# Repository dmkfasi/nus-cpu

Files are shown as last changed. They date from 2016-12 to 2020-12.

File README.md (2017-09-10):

# nus-cpu

This is my own yet another attempt to re-create Nintendo 64 motherboard for a portable, tablet or bartop mod.

I am going after for as much as possible: modular design, reuse of original components, cheapest production costs and the best visual display picture.

There are many bright minds out there whose ideas I try to adopt and develop further. But since I lack of expertise on several electronics topics, this whole thing definately will need some tune up.

Feel free to use, share and modify!

# Work in progress
Schematics is not verified so far, but it looks complete and legit and came from a more or less reliable source off a retrogaming community board. Everything has been broken down into following components:
* CPU-RCP defines core:
    * CPU to RCP connections;
    * RCP to PIF (Nintendo peripherials controller);
    * PIF to Controller Pak;
    * Power rails, ENABLE delay and /COLDRESET circuit, decoupling capacitors;
    * and breakout connections to external peripherial devices:
        * Gamepak port, 50pin;
        * RDRAM interface, 30pin;
        * Audio DAC, 4pin;
        * Video DAC, 10pin;
        * and Controller pak (two players), 4pin.
* RCP-RDRAM defines RAM interface:
    * Uses of two or four chips:
        * 2 of RDRAM18;
        * 4 of RDRAM18;
        * 2 of RDRAM36.
    * and onboard MX8330 clock generator;
* RCP-CART defines Gamepak interface, simple board with flat cable connector;
* RCP-SND defines audio output interface, either usage of B9480F or any other DAC and amplifier;
* RCP-VDC will define video interface.

# PCB design and production files
* CPU-RCP is 4 layer board, finished, Gerber files are included;
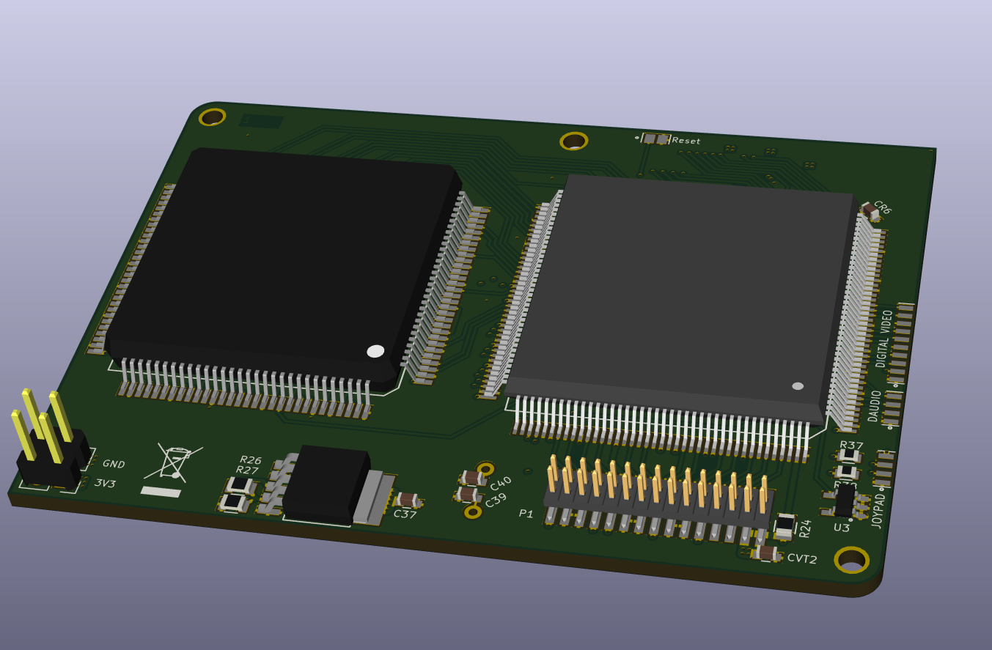
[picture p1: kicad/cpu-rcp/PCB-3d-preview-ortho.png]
Core Board

* RCP-RDRAM is 4 layer board, finished, Gerber files are included;
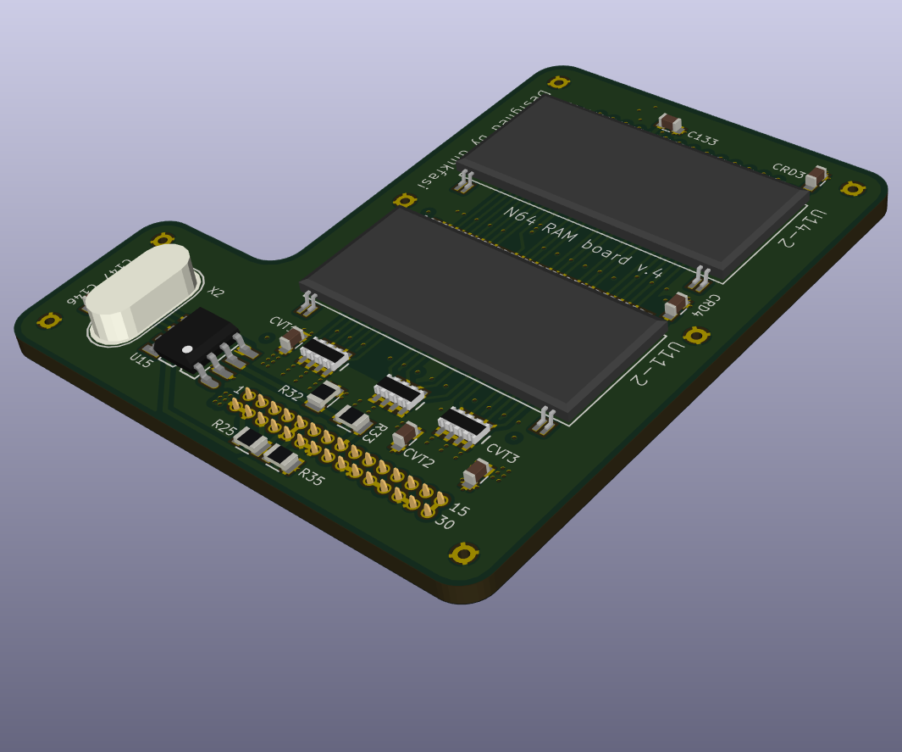
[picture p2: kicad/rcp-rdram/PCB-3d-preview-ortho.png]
RDRAM Board

* RCP-CART is 2 layer board, finished, Gerber files are included;
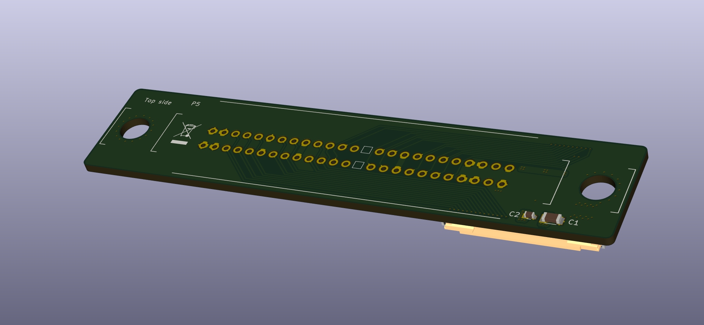
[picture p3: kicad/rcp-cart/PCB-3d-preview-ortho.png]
Gamepak Board

* RCP-SND is not started yet;
* RCP-VDC is not started yet;

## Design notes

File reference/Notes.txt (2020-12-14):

4:3 5 inch LCD by Innolux ZJ050NA-08C, 50 pin parallel RGB

Pullup resistors on all four port game controllers to boot

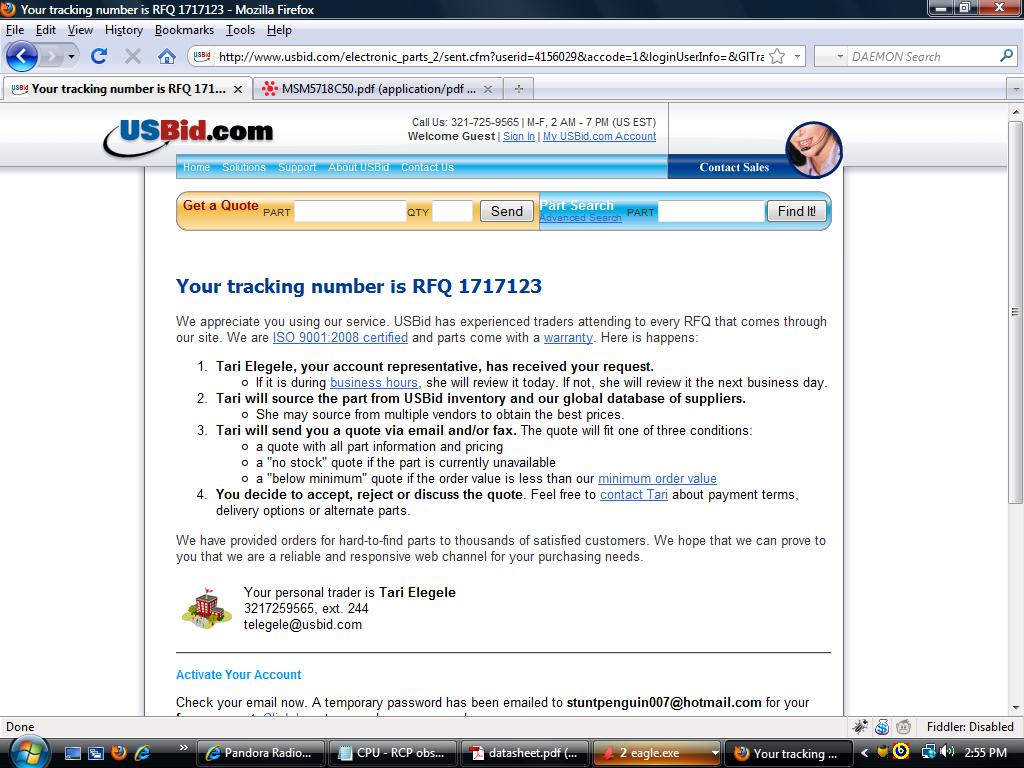
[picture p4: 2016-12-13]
reference/Schematics/N64 EAGLE schematics/Pics/quote.jpg

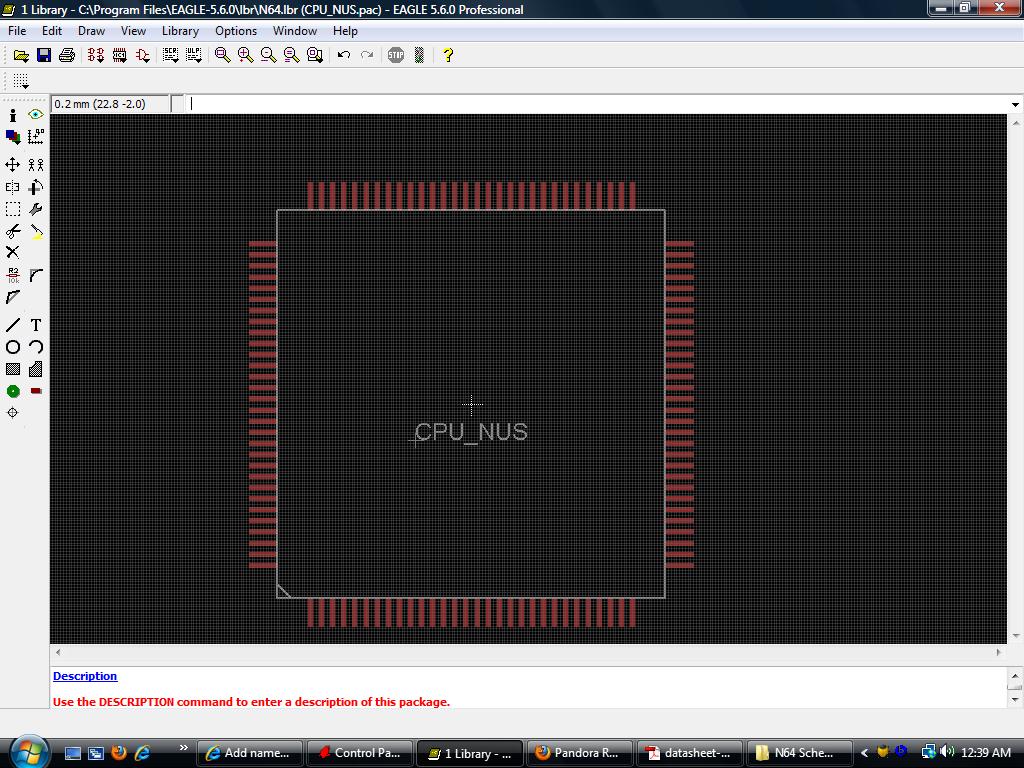
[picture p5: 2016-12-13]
reference/Schematics/N64 EAGLE schematics/Pics/CPU_NUS.jpg

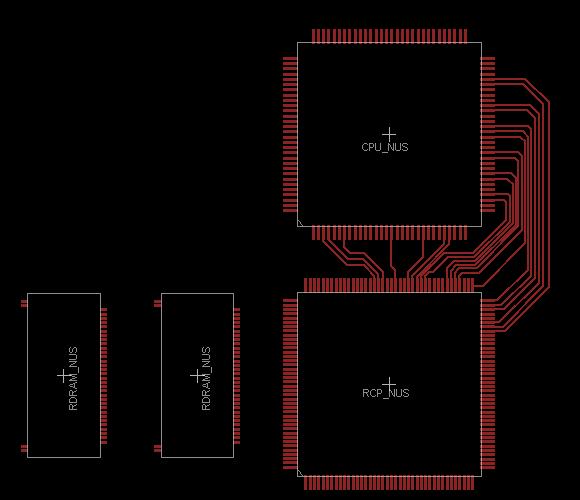
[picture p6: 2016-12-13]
reference/Schematics/N64 EAGLE schematics/Pics/alpha 1.jpg

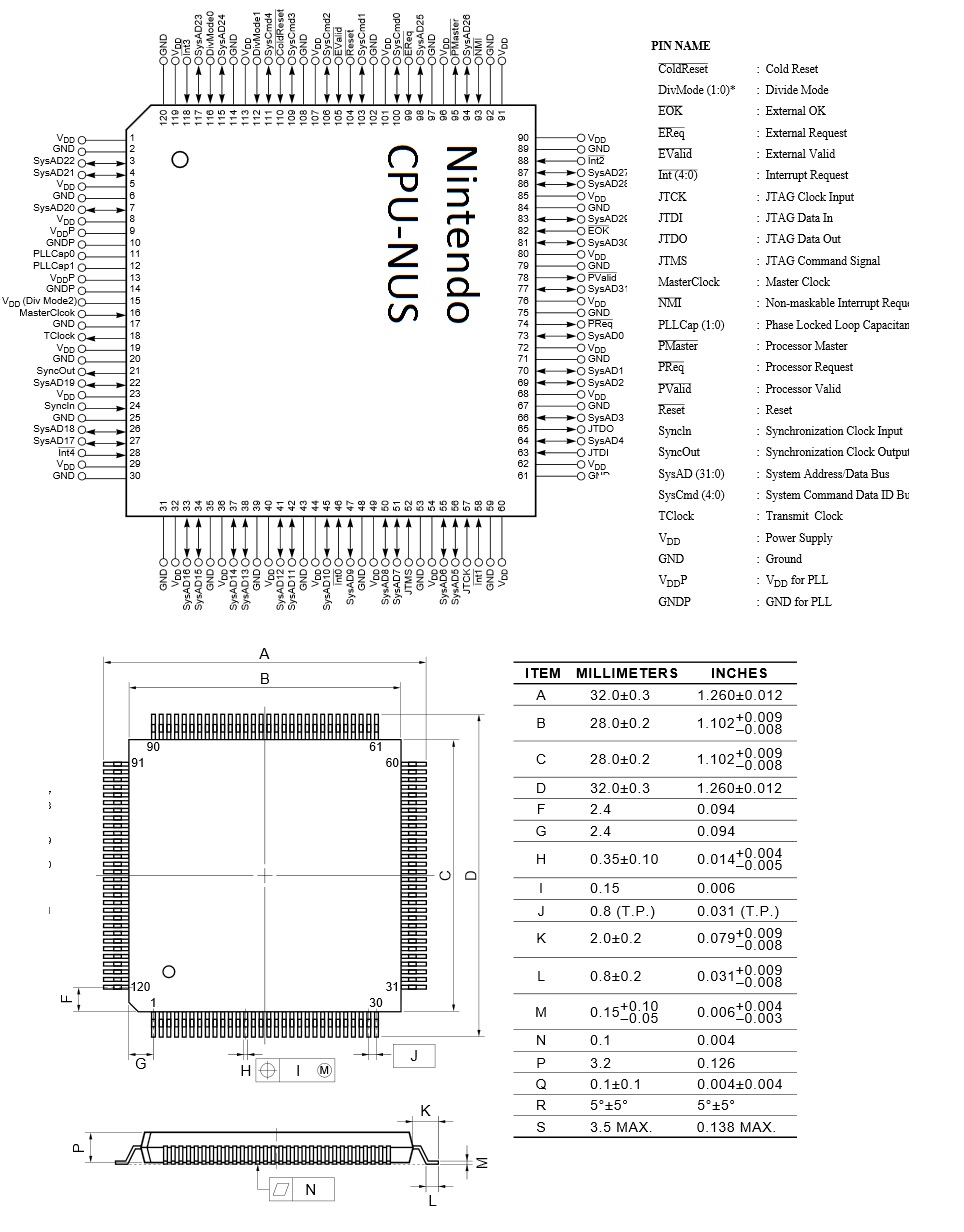
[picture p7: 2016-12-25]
reference/Pinouts/CPU-NUS-Pinout.jpg

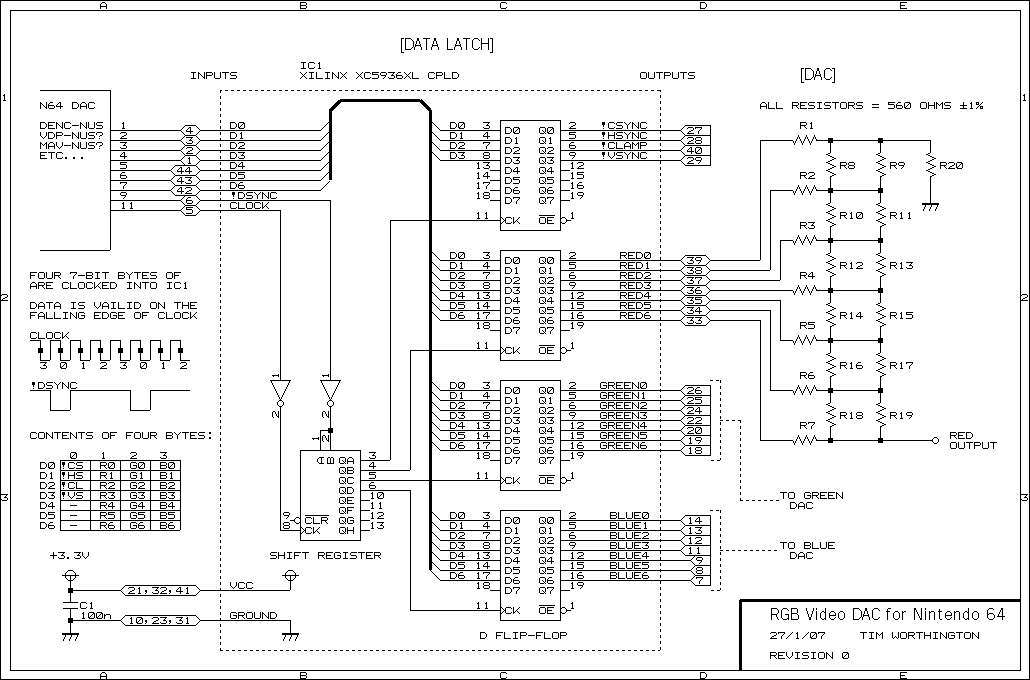
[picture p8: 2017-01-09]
reference/Schematics/n64rgb-serial-to-parallel.png

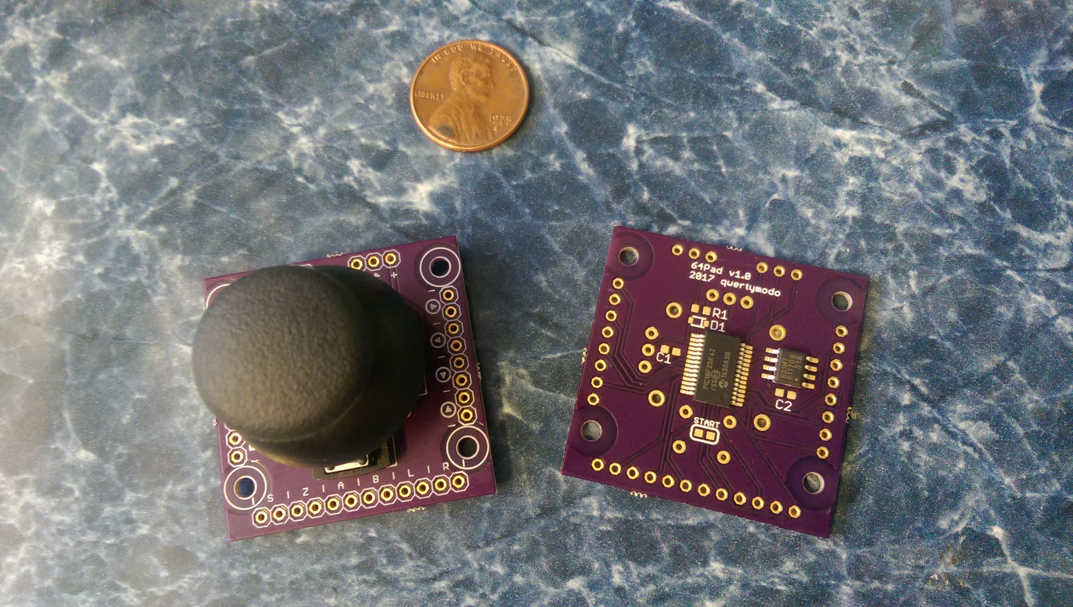
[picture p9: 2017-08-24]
reference/PCB-Designs/rf8QZWV.jpg

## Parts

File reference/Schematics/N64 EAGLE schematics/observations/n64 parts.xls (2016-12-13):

Bill of materials for an early-model NTSC Nintendo 64 motherboard (NUS-004), the one with the original "VDC-NUS" chip that does RGB
 |  | Part | Value | Desc | Side | Package
 | IC | U1 | 9480F | Audio DAC | Top | SOIC-8 | y
 |  | U2 | AMP-NUS | Audio Amp | Top | SOIC-14 | y
 |  | U3 | 2875 | Unknown ( 28g9) (2875) | Top | sot something
 |  | U4 | VDC-NUS | Video DAC | Top | SOIC-24 | y
 |  | U5 | ENC-NUS | Video Encoder | Top | SOIC-14 | y
 |  | U6 | PIF-NUS | Security Chip | Top | SOICW-28 | y
 |  | U7 | MX8330 | RAM Clock generator | Top | SO8 | y
 |  | U8 | LC125 | tristate | Top | QSOP14 | y
 |  | U9 | RCP-NUS | Reality Coprocessor | Top | PQFP160 | y
 |  | U10 | CPU-NUS | MIPS 4300i CPU | Top | QPF120 | y
 |  | U11 | RDRAM18-NUS | 18Mbit RDRAM (2meg byte) | Top | SHP32 | y
 |  | U12 | 7VZ5 | ADJ Voltage Reg | Top | TO something
 |  | U13 | 7805 | 5V Reg | Top | TO something
 |  | U14 | RDRAM18-NUS | 18Mbit RDRAM (2meg byte) | Top | custom | y
 |  | U15 | MX8330 | RAM Clock generator | Top | SO8 | y
 | Switches | SW1 | DPDT | Power Switch | Top | x
 |  | SW2 | SPSP Momentary | Reset Switch | Top | x
 | Connectors | P1 | 36 Pin | Expansion Pack connector | Top | x
 |  | P2 |  | Controller plug | Top | x
 |  | P3 |  | Controller plug | Top | x
 |  | P4 | 6 Pin | Power connetctor | Top | x
 |  | P5 | 50 Pin | Cartridge connector | Top | x
 |  | P6 |  | Not installed? |  | x
 |  | P7 |  | A/V connector | Top | x
 |  | P8 |  | Heatsink Standoff | Top | x
 |  | P9 |  | Heatsink Standoff | Top | x
 | Xtals | X1 |  | Oscillator for RAM? | Top | x
 |  | X2 |  | Oscillator for RAM? | Top | x
 | Fets? | DA1 | MU | Controller | Bottom | x
 |  | DA2 | not present | ??? |  | x
 |  | DA3 | MU | Controller | Bottom | x
 |  | DA4 | not present | ??? |  | x
 |  | DA5 | MU | A/V | Bottom | x
 |  | DA6 | MO | A/V | Bottom | x
 |  | DA7 | MU | A/V | Bottom | x
 |  | DA8 | MO | A/V | Bottom | x
 | Diodes | D1 | 20 |  | Bottom | x
 |  | D2 | 20 |  | Bottom | x
 |  | D3 | Red | Power LED | Top | x
 |  | D4 | M1T | 4 leads | Bottom | x
 |  | D5 | M1T | 4 leads | Bottom | x
 | Fuses | FIL1 | Fuse | Controller | Bottom | x
 |  | FIL2 | Fuse | Controller | Bottom | x
 |  | FIL3 | Fuse | Controller | Bottom | x
 |  | FIL4 | Fuse | Controller | Bottom | x
 |  | FIL5 | Fuse | Controller | Bottom | x
 |  | FIL6 | Fuse | Controller | Bottom | x
 |  | FIL7 | Fuse | Controller | Bottom | x
 |  | FIL8 | Fuse | Controller | Bottom | x
 | Other | Q1 |  | Not installed | Bottom | x
 |  | L5 |  | Not installed | Bottom | x
 |  | L6 |  | Not installed | Bottom | x
 | Resistors | R1 | not present | pulldown on q circuit | Bottom | xx
 |  | R2 | 2k0 (202) | pullup near u2 | Bottom | xx
 |  | R3 | 30k (303) | part of RC for u6 | Bottom | x
 |  | R4 | 68K (683) | part of RC for u6 | Bottom | x
 |  | R5 | 75R (750) | video rc filter (V) | Bottom | x
 |  | R6 | 75R (750) | video rc filter (Y) | Bottom | x
 |  | R7 | 75R (750) | video rc filter (c ) | Bottom | x
 |  | R8 | 110R (111) | output filter on DAC | Bottom | x
 |  | R9 | 110R (111) | output filter on DAC | Bottom | x
 |  | R10 | 110R (111) | output filter on DAC | Bottom | x
 |  | R11 | 10K (103) | some kind of pullup on video DAC | Bottom | x
 |  | R12 | 820R (821) | pull down thingy on clock line to video amp | Bottom | x
 |  | R13 | 4K3 (432) | on clock line to video amp | Bottom | x
 |  | R14 | not present | rc filter on output of mystery line | Bottom | x
 |  | R15 | Not present | Near Q1 under cart slot | Bottom | x
 |  | R16 | Not present | Near Q1 under cart slot | Bottom | x
 |  | R17 | 1K (102) | filter on cart slot right audio | Bottom | x
 |  | R18 | 10K (103) | Filter between audio DAC and audio amp | Bottom | x
 |  | R19 | 184(180k) | charge resistor for u2 cap | Bottom | xx
 |  | R20 | 10K (103) | Filter between audio DAC and audio amp | Bottom | x
 |  | R21 | 1k0 (102) | filter on cart slot left audio | Bottom | x
 |  | R22 | 47K (473) | pullup on reset switch | Bottom | x
 |  | R23 | 1k0 (102) | pullup on eeprom data | Bottom | x
 |  | R24 | 24R (24.0) | vterm sense to RCP | Bottom | x
 |  | R25 | 130R (1300) | Vref divider | Top | x
 |  | R26 | 316R (3160) | U12 (feedback?) | Top | x
 |  | R27 | 301R (3010) | U12 (feedback?) | Top | x
 |  | R28 | Zero (00R) | clock into video DAC | Bottom | x
 |  | R29 | 4R7 (4.7) |  | Bottom | x
 |  | R30 | 4R7 (4.7) |  | Bottom | x
 |  | R31 | 75R (750) | LED resistor | Bottom | x
 |  | R32 | 150R (1500) | U15 | Top | x
 |  | R33 | 33R (33.0) | U15 | Top | x
 |  | R34 | 47K (473) |  | Bottom | x
 |  | R35 | 390R (3900) | Vref divider | Top | x
 |  | R36 | 51k (513) | filteron fsel? | Bottom | x
 |  | R37 | 750R (751) | filter/pullup on controller 1 | Bottom | x
 |  | R38 | 750R (751) | filter/pullup on controller 2 | Bottom | x
 |  | R39 | 750R (751) | filter/pullup on controller 3 | Bottom | x
 |  | R40 | 750R (751) | filter/pullup on controller 4 | Bottom | x
 |  | R41
 |  | R42
 |  | R43
 |  | R44
 |  | R45
 |  | R46
 |  | R47
 |  | R48
 |  | R49
 |  | R50
 |  | R51
 |  | R52
 |  | R53 | 130R (131) | filter/pullup on controller 1 | Bottom | x
 |  | R54 | 130R (131) | filter/pullup on controller 2 | Bottom | x
 |  | R55 | 130R(131) | filter/pullup on controller 3 |  | x
 |  | R56 | 130R(131) | filter/pullup on controller 4 |  | x
 |  | R57 | 1k0 (102) |  | Bottom | x
 |  | R58 | 1k0 (102) |  | Bottom | x
 | Capacitors | C1 | 100nF | d | Bottom
 |  | C2 | 100nF | d | Bottom
 |  | C3 | 100nF | d | Bottom
 |  | C4 | .47uF | d | Bottom
 |  | C5 | 1uF | something power related on r3000 | Bottom
 |  | C6 | 230pF | something power related on r3000 | Bottom
 |  | C7 | 230pF | something power related on r3000 | Bottom
 |  | C8 | 1nF | something power related on r3000 | Bottom
 |  | C9 | 100nF | something power related on r3000 | Bottom
 |  | C10 | 1uF | d | Bottom
 |  | C11 | 47pF | video output filter (c ) | Bottom
 |  | C12 | 47pF | video output filter (y) | Bottom
 |  | C13 | 47pF | video output filter (v) | Bottom
 |  | C14 | 47nF | something on c line before filter | Bottom
 |  | C15 | 220 | video (v) out Can | Top
 |  | C16 | 220 | video (y) out Can | Top
 |  | C17 | 100nF | d | Bottom
 |  | C18 | 100nF | d | Bottom
 |  | C19 | 100nF | d | Bottom
 |  | C20 | 100nF | d | Bottom
 |  | C21 | 100nF | some filter on clock going into u5 | Bottom
 |  | C22 | not present | mystery ouput | Bottom
 |  | C23 | 330pF | left audio output | Bottom
 |  | C24 | 33 | something on U2 Can | Top
 |  | C25 | 10 | l audio Can | Top
 |  | C26 | 10 | r audio Can | Top
 |  | C27 | 100nF | d | Bottom
 |  | C28 | 33 | something on U2 Can | Top
 |  | C29 | 100nF | cap on right_audio | Bottom
 |  | C30 | 100nF | cap on left_audio | Bottom
 |  | C31 | 100nF | caps coming out of U1 | Bottom
 |  | C32 | 100nF | caps coming out of U2 | Bottom
 |  | C33 | 47uF | ref on U1 Can | Top
 |  | C34 | 10 | something on U2 Can | Top
 |  | C35 | 100nF | d | Bottom
 |  | C36 | 100nF | d | Bottom
 |  | C37 | 1uF? | I lost it d | Bottom
 |  | C38 | 10nF | d | Bottom
 |  | C39 | 47pF | xtal cap | Bottom
 |  | C40 | 47pF | xtal cap | Bottom
 |  | C41 | 100nF | d | Bottom
 |  | C42 | 10nF | d | Bottom
 |  | C43 | 1uF | d | Bottom
 |  | C44 | 1uF | d | Bottom
 |  | C45 | 100nF | d | Bottom
 |  | C46 | 10nF | d | Bottom
 |  | C47 | 100nF | d | Bottom
 |  | C48 | 10nF | d | Bottom
 |  | C49 | 100nF | d | Bottom
 |  | C50 | 10nF | d | Bottom
 |  | C51 | 100nF | d | Bottom
 |  | C52 | 10nF | d | Bottom
 |  | C53 | 1uF | d | Bottom
 |  | C54 | 100nF | d | Bottom
 |  | C55 | 100nF | d | Bottom
 |  | C56 | 100nF | d | Bottom
 |  | C57 | 100nF | d | Bottom
 |  | C58 | 100nF | d | Bottom
 |  | C59 | 1uF | d | Bottom
 |  | C60 | 1uF | d | Bottom
 |  | C61 | 1uF | d | Bottom
 |  | C62 | 1uF | d | Bottom
 |  | C63 | 1uF | d | Bottom
 |  | C64 | 100nF | d | Bottom
 |  | C65 | 1uF | d | Bottom
 |  | C66 | 1uF | d | Bottom
 |  | C67 | 570pF | d | Bottom
 |  | C68 | 10nF | d | Bottom
 |  | C69 | 100nF | d | Bottom
 |  | C70 | 100nF | d | Bottom
 |  | C71 | 100nF | d | Bottom
 |  | C72 | 100nF | d | Bottom
 |  | C73 | 47uF | dv Can | Top
 |  | C74 | 1uF | d | Bottom
 |  | C75 | 100nF | d | Bottom
 |  | C76 | 100nF | d | Bottom
 |  | C77 | 100nF | d | Bottom
 |  | C78 | 100nF | d | Bottom
 |  | C79 | 1uF | d | Bottom
 |  | C80 | 10nF | d | Bottom
 |  | C81 | 47uF | d3 Can | Top
 |  | C82 | 1uF | d | Bottom
 |  | C83 | 100nF | d | Bottom
 |  | C84 | 1uF | d | Bottom
 |  | C85 | 100nF? | I lost it d | Bottom
 |  | C86 | 100nF | d | Bottom
 |  | C87 | 100nF | d | Bottom
 |  | C88 | 10nF | d | Bottom
 |  | C89 | 1uF | d | Bottom
 |  | C90 | 10nF | d | Bottom
 |  | C91 | 10nF | d | Bottom
 |  | C92 | 1uF | d | Bottom
 |  | C93 | 100nF | d | Bottom
 |  | C94 | 100nF | d | Bottom
 |  | C95 | 1uF | d | Bottom
 |  | C96 | 10nF | d | Bottom
 |  | C97 | 1uF | d | Bottom
 |  | C98 | 1uF | d | Bottom
 |  | C99 | 100nF | d | Bottom
 |  | C100 | 10nF | d | Bottom
 |  | C101 | 100nF | d | Bottom
 |  | C102 | 10nF | d | Bottom
 |  | C103 | 100nF | d | Bottom
 |  | C104 | 100nF | d | Bottom
 |  | C105 | 100nF | d | Bottom
 |  | C106 | 100nF | d | Bottom
 |  | C107 | 100nF | d | Bottom
 |  | C108 | 100nF | d | Bottom
 |  | C109 | 70pF | d | Bottom
 |  | C110 | 100nF | d | Bottom
 |  | C111 | 100nF | d | Bottom
 |  | C112 | 1uF | d | Bottom
 |  | C113 | 100nF | d | Bottom
 |  | C114 | 1uF | d | Bottom
 |  | C115 | 100nF | d | Bottom
 |  | C116 |  | d | Bottom
 |  | C117 | 1uF | d | Bottom
 |  | C118 | 1uF | d | Bottom
 |  | C119 | 1uF | d | Bottom
 |  | C120 | 100nF | d | Bottom
 |  | C121 | 100nF | d | Bottom
 |  | C122 | 330pF | right audio output | Bottom
 |  | C123 | 200nF | CIC chip | Bottom
 |  | C124 | 1uF | output filter on video DAC (C ) | Bottom
 |  | C125 | 1uF | output filter on video dac (y) | Bottom
 |  | C126 | 1uF | output filter on video dac (v) | Bottom
 |  | C127 | .47uF | CIC chip | Bottom
 |  | C128 | 10 | RC clock for CIC Can | Top
 |  | C129 | 100nF | d | Bottom
 |  | C130 | 47uF | d5 Can | Top
 |  | C131 | 47uF | d3 Can | Top
 |  | C132 | 1uF | d | Bottom
 |  | C133 | 1uF | d | Bottom
 |  | C134 | 47uF | d3 Can | Top
 |  | C135 | 1uF | d | Bottom
 |  | C136 | 100nF | d | Bottom
 |  | C137 | 100nF | d | Bottom
 |  | C138 | 1uF | d | Bottom
 |  | C139 | 100nF | d | Bottom
 |  | C140 | 47uF | d3 Can | Top
 |  | C141 | 47uF | d3 Can | Top
 |  | C142 | 33 | d12 Can | Top
 |  | C143 | 100nF | something on video DAC | Bottom
 |  | C144 | 200nF | something clock related near U15 | Bottom
 |  | C145 | 47uF | dv Can | Top
 |  | C146 | 47pF | xtal cap | Bottom
 |  | C147 | 47pF | xtal cap | Bottom
 |  | C148 | 100nF | d | Bottom
 |  | C149 | 1uF | d | Bottom
 |  | C150 | 100nF | d | Bottom
 |  | C151 | 570pF | d | Bottom
 |  | C152 | 10nF | d | Bottom
 |  | C153 | 10nF | d | Bottom
 |  | C154 | 470pF | d | Bottom
 |  | C155 | 70pF | controller 1 | Bottom
 |  | C156 | 70pF | controller 2 | Bottom
 |  | C157 | 70pF | controller 3 | Bottom
 |  | C158 | 10nF | controller 4 | Bottom
 |  | C159 | 10nF | d | Bottom
 |  | C160 | 120nF | d12 | Top
 |  | C161 | 120nF | d3 | Top
 |  | C162 | 10nF | d | Bottom
 |  | C163 | 10nF | d | Bottom
 |  | C164 | 10nF | d | Bottom
 |  | C165 | 10nF | d | Bottom
 |  | C166 | 10nF | d | Bottom
 |  | C167 | 10nF | d | Bottom
 |  | C168 | 10nF | d | Bottom
 |  | C169 | 10nF | d | Bottom
 |  | C170 | 10nF | d | Bottom
 |  | C171 | not present |  | Bottom
 |  | C172 | not present | d | Bottom
 |  | C173 | not present | d | Bottom
 |  | C174 | not present | d | Bottom
 |  | C175 | not present | d | Bottom
 |  | C176 | not present | decouple for ALEH? | Bottom
 |  | C177 | not present | d | Bottom
 |  | C178 | not present | d | Bottom
 |  | 179 |  | d
 | controller | R1 | 1M0 (105)
 |  | R2 | 5k6 (562)
 |  | R3 | 130R (131)
 |  | R4 | 150K (154)

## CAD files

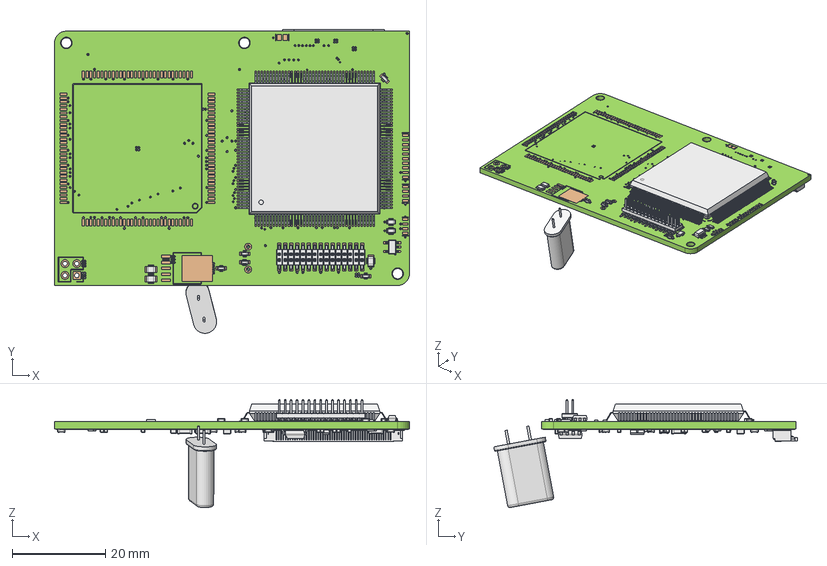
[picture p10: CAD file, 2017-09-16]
freecad/CoreBoard.fcstd
76.2 x 65.2 x 23.2 mm
Board
R2
R3
R4
R22
R23
R34
R36
R37
R38
R28
C5
C128
C134
C81
C73
P1
DA1
X1
U3
U7
C144
CC1
CC2
CC3
CC4
CC5
CC6
CC7
CC8
CC9
CR2
CR3
CR4
CR5
CR6
CR7
CR8
CR9
CR10
CR11
CR12
CR13
CR14
CR15
CU6
CU7
CU8
CVR1
CVR2
CVT2
CC10
CC11
CC12
CR16
C37
CR17
C9
C7
CR1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

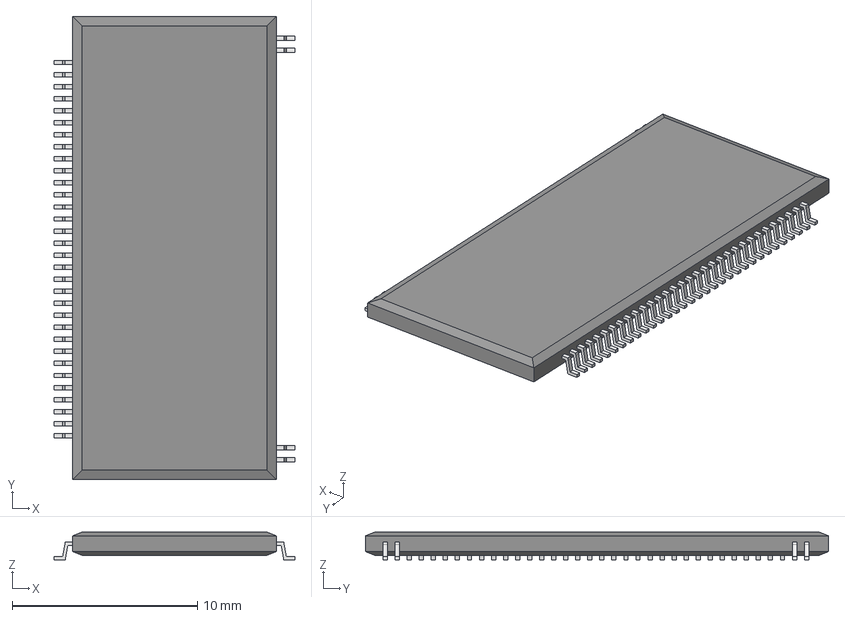
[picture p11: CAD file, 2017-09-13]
reference/package3d-src/shp-32.stp
13.0 x 25.0 x 1.50 mm
Pins_1-32
Support_Pins_1
Support_Pins_2

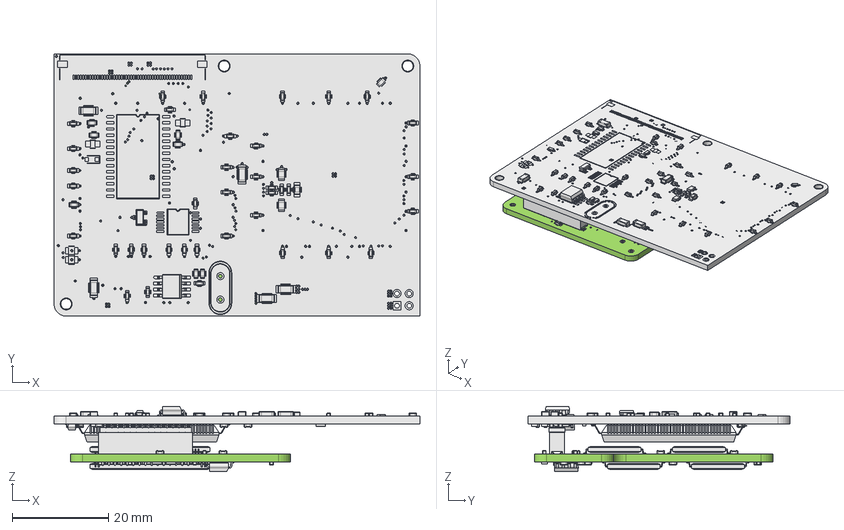
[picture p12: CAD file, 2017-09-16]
freecad/RamBoard.fcstd
76.2 x 54.6 x 13.6 mm
Board
RA1
RA2
RA3
R25
R32
R33
R35
U15
C71
CRD1
CU15
C132
C133
C146
C147
CRD2
CRD3
CRD4
CVT1
CVT2
CVT3
P1
U11-2
U11
U14
U14-2
bPad_107
tPad_108
B_SilkS_36
F_SilkS_37
Board001
R2
R3
R4
R22
R23
R34
R36
R37
R38
bPad_107001
tPad_108001
B_SilkS_36001
F_SilkS_37001
R28
C5
C128
CVT005
C134
C81
C73
P003
DA1
U3
U7
C144
CC1
CC2
CC3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

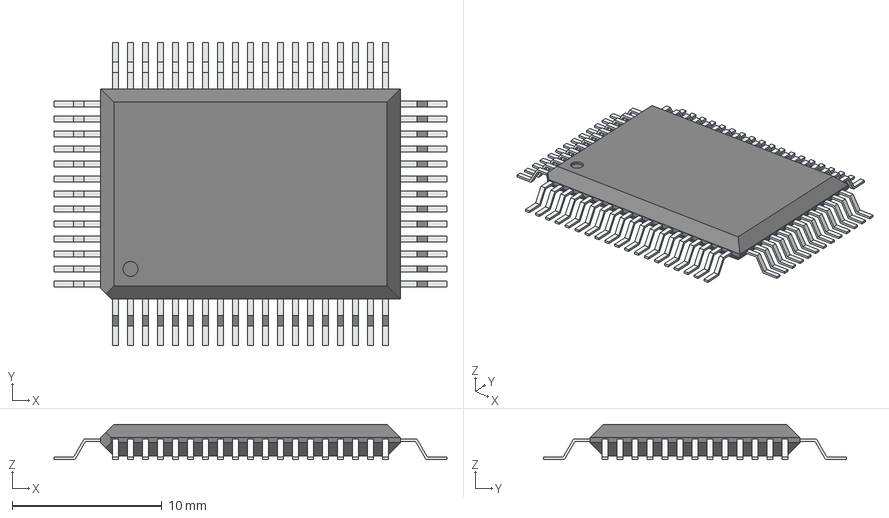
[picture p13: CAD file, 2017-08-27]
reference/package3d-src/pqfp-64.FCStd
26.2 x 20.2 x 2.36 mm
Array Left Pin
Mirror Right Pin
Array Front Pin
Mirror Front Pin
Chamfer With Key

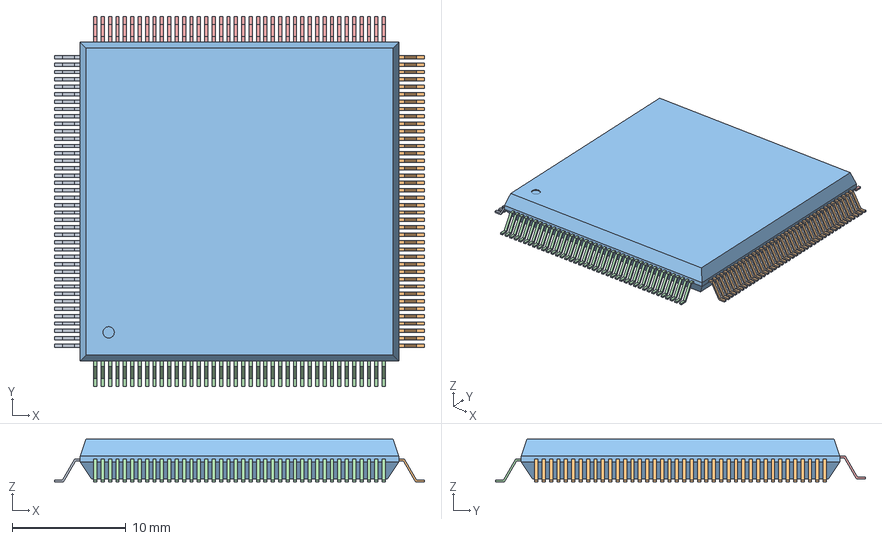
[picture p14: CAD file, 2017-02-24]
reference/package3d-src/qfp-160.FCStd
32.5 x 32.5 x 3.75 mm
Array (Mirror #1)
Array (Mirror #2)
Array (Mirror #3)

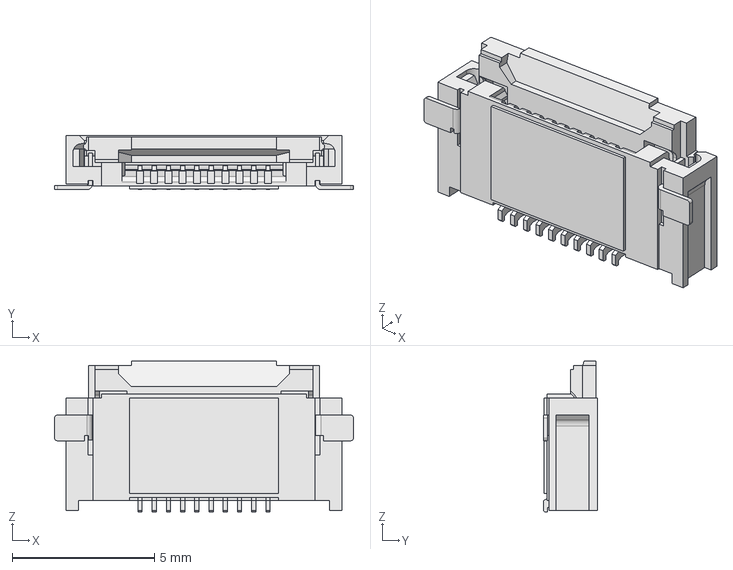
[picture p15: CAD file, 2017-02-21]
reference/package3d-src/molex-505110-1092.FCStd
10.5 x 1.90 x 5.30 mm

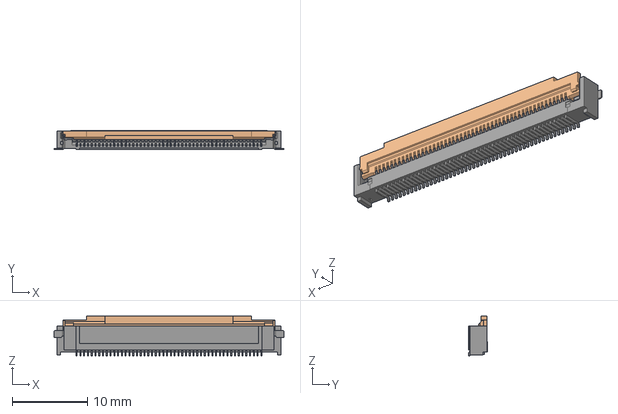
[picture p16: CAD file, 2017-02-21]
reference/package3d-src/molex-502790-5091.FCStd
30.5 x 2.55 x 5.30 mm

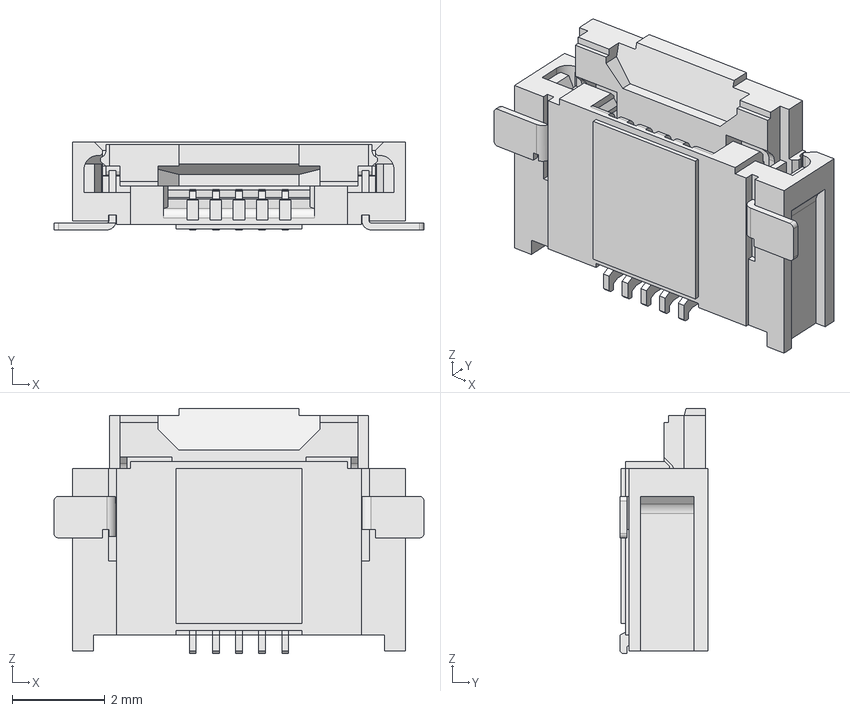
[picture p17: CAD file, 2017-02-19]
reference/package3d-src/molex-505110-0592.FCStd
8.00 x 1.90 x 5.30 mm

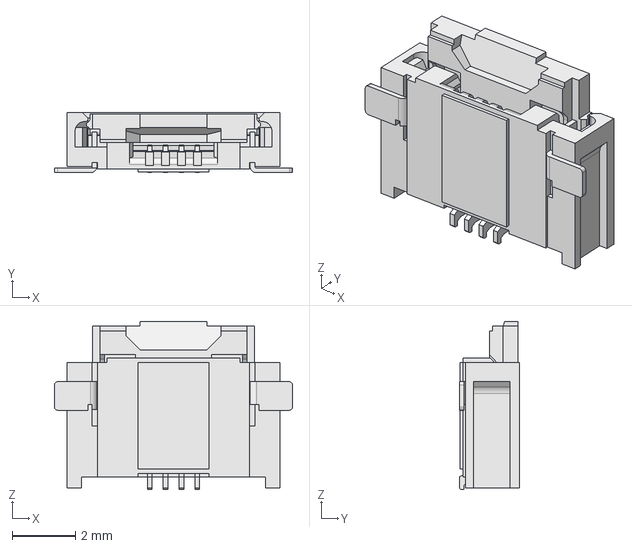
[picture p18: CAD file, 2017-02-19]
reference/package3d-src/molex-505110-0492.FCStd
7.50 x 1.90 x 5.30 mm

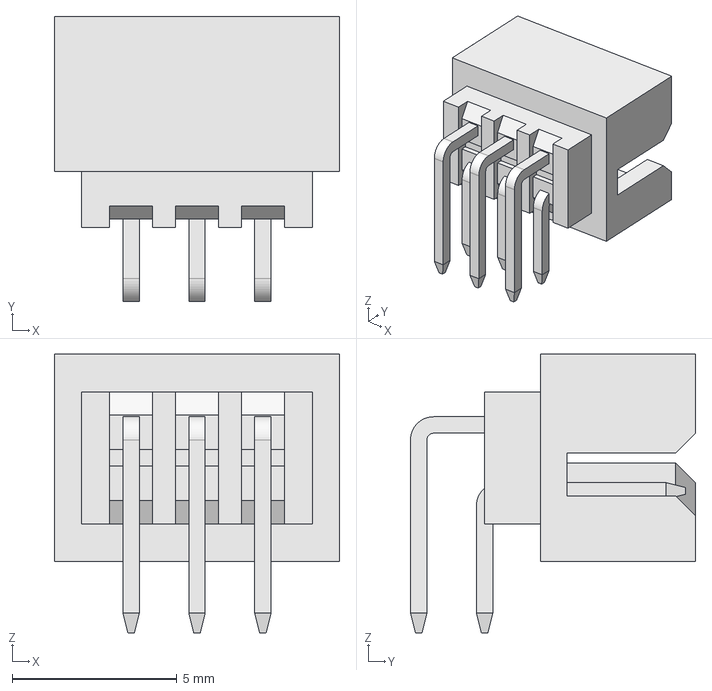
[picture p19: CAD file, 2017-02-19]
reference/package3d-src/molex-87833-0620.FCStd
8.65 x 8.65 x 8.46 mm

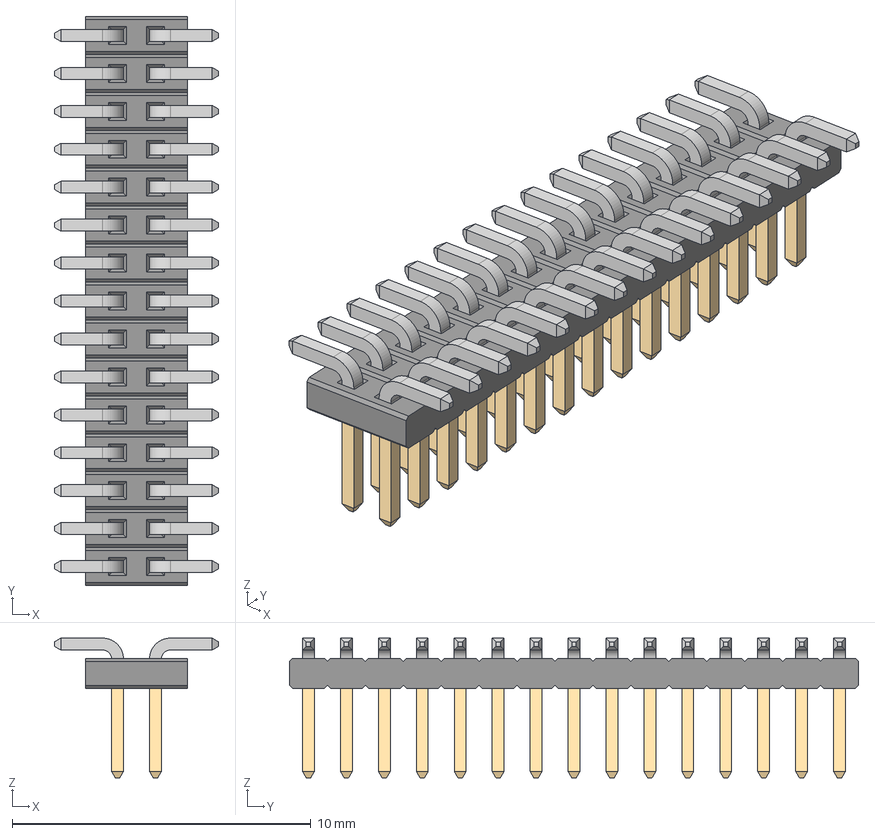
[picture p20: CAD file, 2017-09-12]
reference/package3d-src/m50-3601542_asm.stp
5.50 x 19.1 x 4.68 mm
M50-350-MLD
M50-360-CONTACT x 30

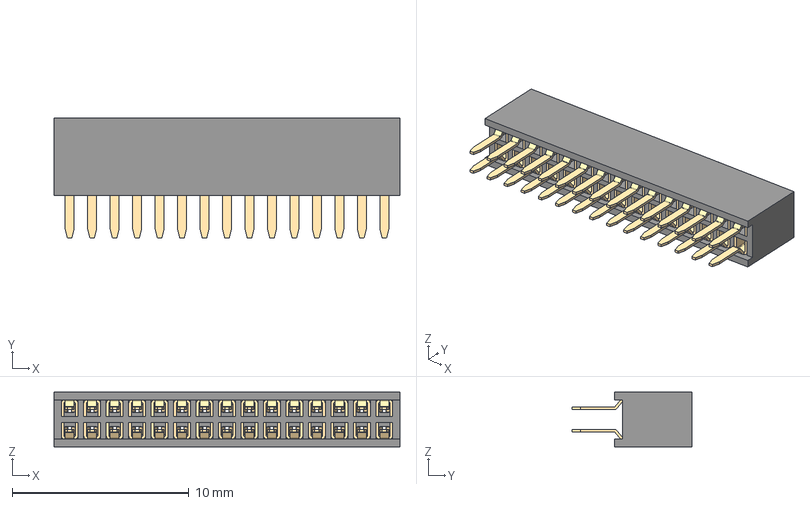
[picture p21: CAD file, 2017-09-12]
reference/package3d-src/m50-3001545_asm.stp
19.6 x 6.80 x 3.10 mm
M50-300-MOULD
M50-300-CONTACT x 30

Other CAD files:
reference/package3d-src/shp-32.FCStd

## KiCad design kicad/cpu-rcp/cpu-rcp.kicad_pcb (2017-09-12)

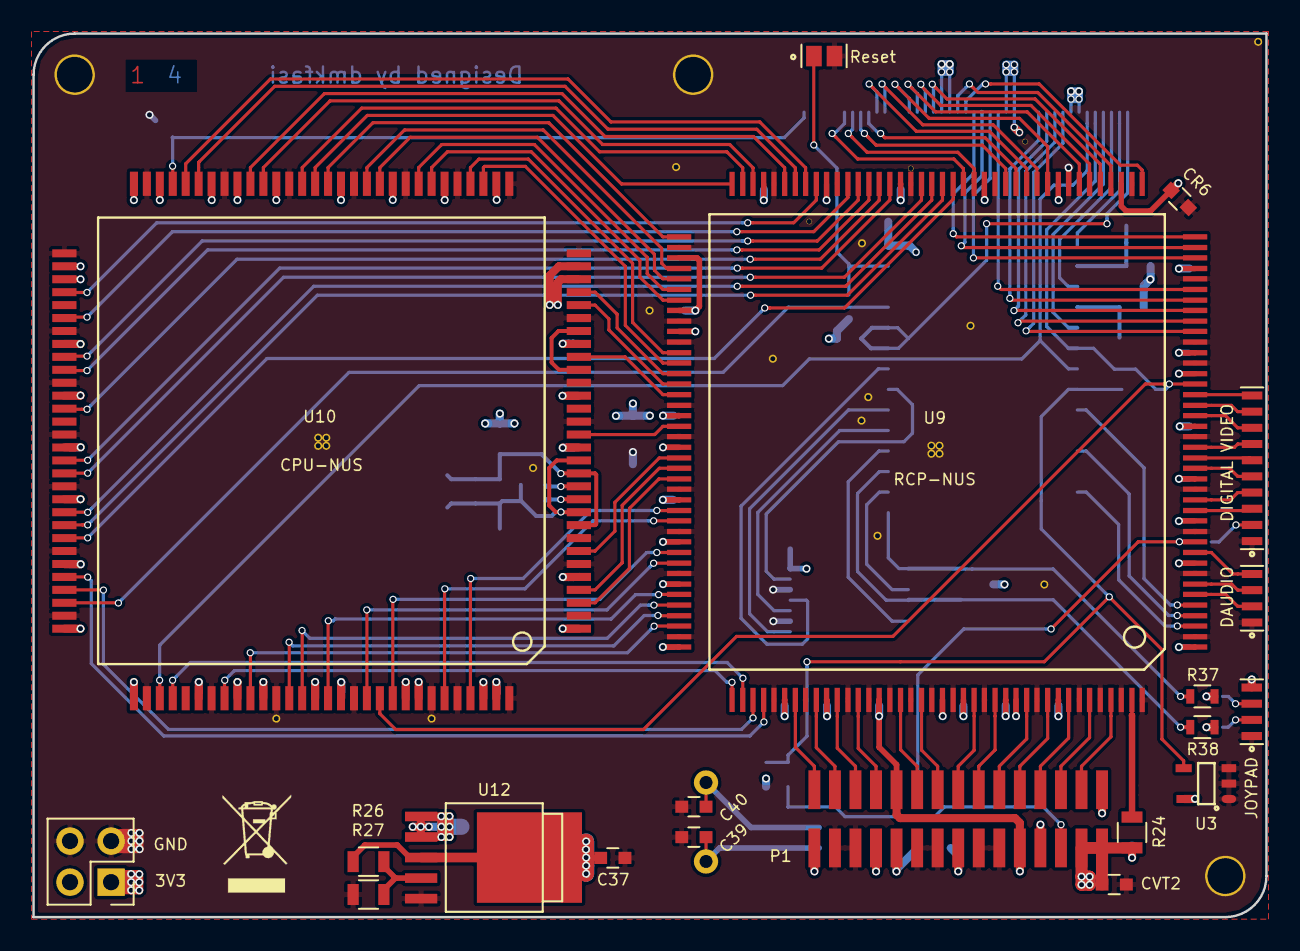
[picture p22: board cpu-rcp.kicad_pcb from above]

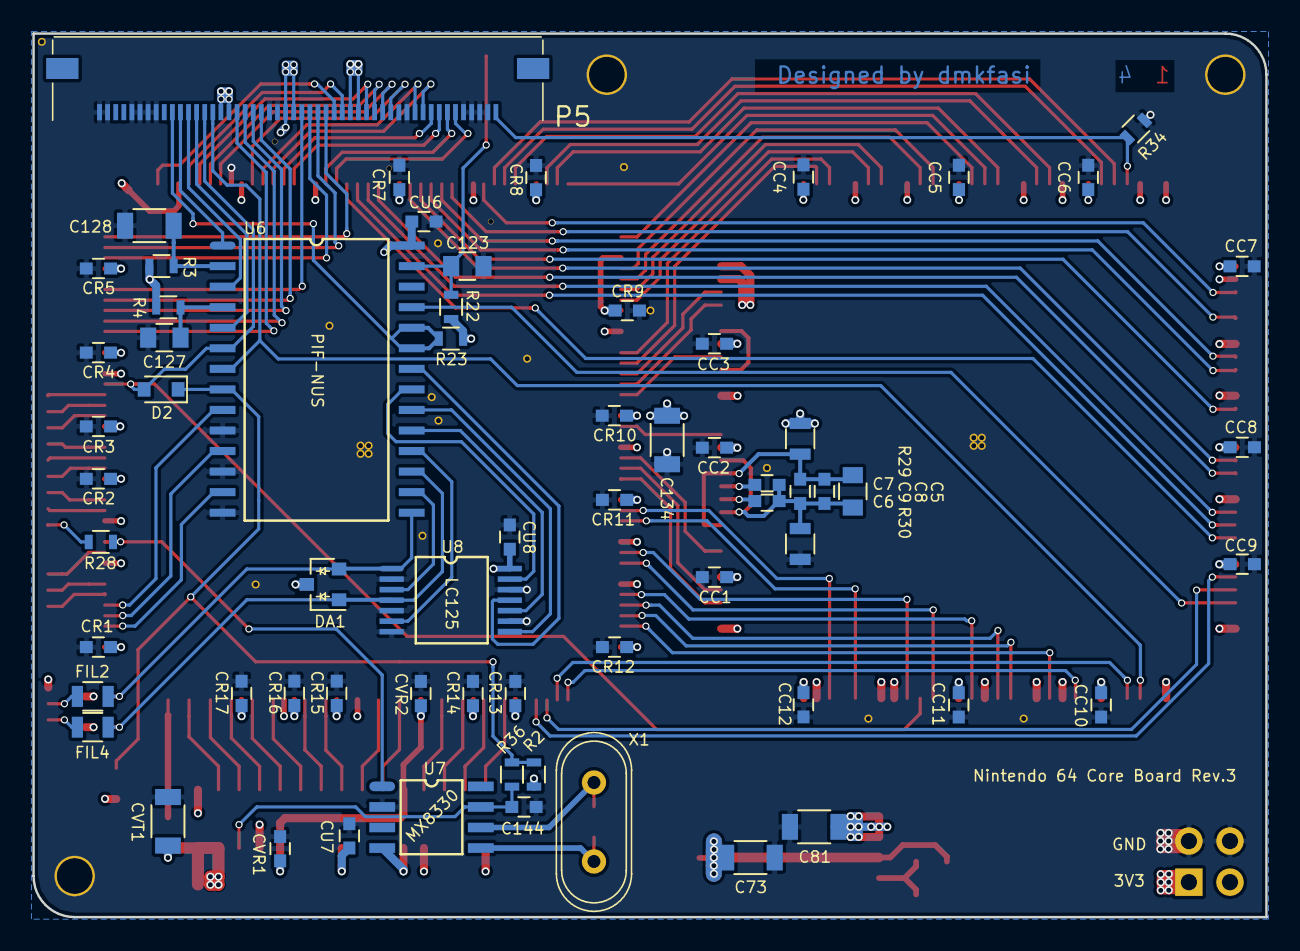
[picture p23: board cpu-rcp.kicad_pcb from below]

Board: 4 copper layers, 76.2 x 54.6 mm, 85 parts (65 on the bottom side), 127 nets.

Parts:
C5: C_0805
C6, C7: 220pF; C_0603
C8, C9, C144: C_0603
C37: .1uF; C_0603
C39, C40: 40pF; C_0603
C73, C81, C134: 68uF; C_1206
C123, C127: ±; C_0805
C128: 10uF; C_1206
CC1, CC2, CC3, CC4, CC5, CC6, CC7, CC8, CC9, CC10, CC11, CC12: .1uF; C_0603
CR1, CR2, CR3, CR4, CR5, CR6, CR7, CR8, CR9, CR10, CR11, CR12, CR13, CR14, CR15, CR16, CR17: .1uF; C_0603
CU6, CU7, CU8: .1uF; C_0603
CVR1, CVR2: .1uF; C_0603
CVT1: 10uF; C_1206
CVT2: .1uF; C_0603
D2: ±; D_0805
DA1: BAC54; D_SOT-23_AAK
DAUD1: DAUDIO; Connectors_GS4
DCIN1: Power Input; Pin_Header_Straight_2x02_Pitch2.54mm
DVO1: DIGITAL VIDEO; Connectors_GS10
FIL2, FIL4: 3.3uH; L_0805
JOY1: JOYPAD; Connectors_GS4
P1: RDRAM-EDGE; rdram-edge-smt
P5: 502790-5091; connector-molex-502790-5091
R2: 2K; R_0603
R3: 30K; R_0603
R4: 68K; R_0603
R22, R34: 47K; R_0603
R23: 1K; R_0603
R24: 24R; R_0805
R26: 316; R_0805
R27: 301; R_0805
R28: 0R; R_0603
R29, R30: 4R7; R_0805
R36: 51K; R_0603
R37, R38: 750R; R_0603
SW1: Reset; Connectors_GS2
U3: U3; u3-sot-23-5
U6: PIF-NUS; pif-nus-so-28w
U7: MX8330; mx8330-sop-8
U8: LC125; u8-ssop-14
U9: RCP-NUS; rcp-nus-qfp-160
U10: CPU-NUS; cpu-nus-qfp-120
U12: PQ7VZ5; d-pak-5
X1: 14.318MHz; Crystal_HC-49V

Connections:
+3V3: C81.1, C134.1, CC1.1, CC2.1, CC3.1, CC4.1, CC5.1, CC6.1, CC7.1, CC8.1, CC9.1, CC10.1, CC11.1, CC12.1, CR1.1, CR2.1, CR3.1, CR4.1, CR5.1, CR6.1, CR7.1, CR8.1, CR9.1, CR10.1, CR11.1, CR12.1, CR13.1, CR14.1, CR15.1, CR16.1, CR17.1, CU6.1, CU7.1, CU8.1, DA1.3, DCIN1.1, DCIN1.2, JOY1.4, P1.15, P1.19, P1.23, P1.26, P1.27, P1.30, P5.18, P5.19, P5.26, P5.27, P5.34, P5.35, R2.1, R3.2, R4.2, R22.1, R23.1, R29.2, R37.1, R38.1, U3.5, U6.28, U7.4, U8.14, U9.1, U9.9, U9.13, U9.17, U9.22, U9.27, U9.29, U9.37, U9.43, U9.49, U9.56, U9.64, U9.71, U9.77, U9.83, U9.88, U9.90, U9.98, U9.101, U9.106, U9.110, U9.114, U9.120, U9.126, U9.130, U9.141, U9.143, U9.147, U9.148, U9.152, U10.1, U10.5, U10.15, U10.19, U10.23, U10.28, U10.29, U10.32, U10.36, U10.40, U10.44, U10.49, U10.52, U10.54, U10.58, U10.60, U10.62, U10.63, U10.68, U10.72, U10.76, U10.80, U10.85, U10.90, U10.91, U10.96, U10.99, U10.101, U10.105, U10.107, U10.112, U10.113, U10.118, U10.119, U12.1, U12.2
//EOK: U9.60, U10.82
//PVALID: U9.62, U10.78
/CART_READ: P5.20, U9.44
/CART_WRITE: P5.16, U9.46
/COLDRESET: D2.2, P5.37, U6.6, U9.26, U10.110
/DSYNC: DVO1.3, U9.14
/INT0: U9.80, U10.46
/INT2: U6.25, U10.88
/MasterClock: U9.99, U10.16
/NMI: P5.36, U6.7, U10.93
/SYSAD0: U9.66, U10.73
/SYSAD1: U9.67, U10.70
/SYSAD2: U9.68, U10.69
/SYSAD3: U9.69, U10.66
/SYSAD4: U9.72, U10.64
/SYSAD5: U9.73, U10.56
/SYSAD6: U9.74, U10.55
/SYSAD7: U9.75, U10.51
/SYSAD8: U9.78, U10.50
/SYSAD9: U9.79, U10.47
/SYSAD10: U9.81, U10.45
/SYSAD11: U9.84, U10.42
/SYSAD12: U9.85, U10.41
/SYSAD13: U9.86, U10.38
/SYSAD14: U9.87, U10.37
/SYSAD15: U9.92, U10.34
/SYSAD16: U9.93, U10.33
/SYSAD17: U9.94, U10.27
/SYSAD18: U9.95, U10.26
/SYSAD19: U9.96, U10.22
/SYSAD20: U9.102, U10.7
/SYSAD21: U9.103, U10.4
/SYSAD22: U9.104, U10.3
/SYSAD23: U9.107, U10.117
/SYSAD24: U9.108, U10.115
/SYSAD25: U9.121, U10.98
/SYSAD26: U9.122, U10.94
/SYSAD27: U9.123, U10.87
/SYSAD28: U9.124, U10.86
/SYSAD29: U9.59, U10.83
/SYSAD30: U9.61, U10.81
/SYSAD31: U9.65, U10.77
/SYSCMD0: U9.118, U10.100
/SYSCMD1: U9.117, U10.103
/SYSCMD2: U9.115, U10.106
/SYSCMD3: U9.112, U10.109
/SYSCMD4: U9.111, U10.111
ADDR: P1.12, U9.153
BCLK: DAUD1.2, U9.6
CART_ADDR00: P5.7, U9.57
CART_ADDR01: P5.9, U9.53
CART_ADDR02: P5.11, U9.51
CART_ADDR03: P5.15, U9.47
CART_ADDR04: P5.23, U9.39
CART_ADDR05: P5.25, U9.35
CART_ADDR06: P5.31, U9.33
CART_ADDR07: P5.33, U9.31
CART_ADDR08: P5.32, U9.32
CART_ADDR09: P5.30, U9.34
CART_ADDR10: P5.24, U9.38
CART_ADDR11: P5.22, U9.40
CART_ADDR12: P5.14, U9.50
CART_ADDR13: P5.10, U9.52
CART_ADDR14: P5.8, U9.54
CART_ADDR15: P5.6, U9.58
CART_ALE_H: P5.21, U9.41
CART_ALE_L: P5.17, U9.45
CIC_CLK: P5.40, U6.1
CIC_IN: P5.38, U6.5
CIC_OUT: P5.39, U6.3
CMD: P1.6, U9.137
DQ0: P1.1, U9.127
DQ1: P1.2, U9.129
DQ2: P1.3, U9.131
DQ3: P1.4, U9.133
DQ4: P1.7, U9.139
DQ5: P1.10, U9.149
DQ6: P1.11, U9.151
DQ7: P1.13, U9.155
DQ8: P1.14, U9.157
EEPROM_DAT: P5.41, R23.2, U6.23, U6.24
ENABLE: D2.1, R2.2, R36.2, U3.4, U6.8
ENABLE_CLK: C144.1, P1.18, R36.1, U7.7
GND: C37.2, C39.2, C40.2, C73.2, C81.2, C123.2, C127.2, C128.2, C134.2, C144.2, CC1.2, CC2.2, CC3.2, CC4.2, CC5.2, CC6.2, CC7.2, CC8.2, CC9.2, CC10.2, CC11.2, CC12.2, CR1.2, CR2.2, CR3.2, CR4.2, CR5.2, CR6.2, CR7.2, CR8.2, CR9.2, CR10.2, CR11.2, CR12.2, CR13.2, CR14.2, CR15.2, CR16.2, CR17.2, CU6.2, CU7.2, CU8.2, CVR1.2, CVR2.2, CVT1.2, CVT2.2, DAUD1.1, DCIN1.3, DCIN1.4, DVO1.1, JOY1.1, P1.21, P1.22, P1.24, P1.25, P1.28, P1.29, P5.2, P5.3, P5.4, P5.5, P5.12, P5.13, P5.28, P5.29, P5.43, P5.44, P5.45, P5.46, P5.49, P5.50, R27.2, R30.2, R34.1, SW1.2, U3.1, U3.2, U3.3, U6.10, U6.12, U6.14, U7.2, U8.2, U8.5, U8.7, U8.9, U8.12, U9.2, U9.8, U9.12, U9.16, U9.21, U9.28, U9.30, U9.36, U9.42, U9.48, U9.55, U9.63, U9.70, U9.76, U9.82, U9.89, U9.91, U9.97, U9.100, U9.105, U9.109, U9.113, U9.119, U9.125, U9.128, U9.132, U9.134, U9.136, U9.138, U9.140, U9.142, U9.145, U9.150, U9.154, U9.156, U9.158, U9.160, U10.2, U10.6, U10.8, U10.17, U10.20, U10.25, U10.30, U10.31, U10.35, U10.39, U10.43, U10.48, U10.53, U10.59, U10.61, U10.67, U10.71, U10.75, U10.79, U10.84, U10.89, U10.92, U10.97, U10.102, U10.108, U10.114, U10.116, U10.120, U12.5
JOY1_DATA: DA1.1, FIL2.1, R37.2, U6.15, U8.1
JOY2_DATA: DA1.2, FIL4.1, R38.2, U6.17, U8.4
JTCK: P5.1, R34.2, U10.57
LRCLK: DAUD1.4, U9.10
unnamed: C5.1, C8.1, C9.1, R29.1, U10.9, U10.13
unnamed: C5.2, C6.2, C7.1, C8.2, C9.2, R30.1, U10.10, U10.14
unnamed: C6.1, U10.11
unnamed: C7.2, U10.12
unnamed: C39.1, U7.5, X1.1
unnamed: C40.1, U7.6, X1.2
unnamed: C123.1, R22.2, SW1.1, U6.27
unnamed: C127.1, R4.1, U6.4
unnamed: C128.1, R3.1, U6.2
unnamed: DVO1.2, R28.2
unnamed: FIL2.2, JOY1.3
unnamed: FIL4.2, JOY1.2
unnamed: R24.2, U9.159
unnamed: R26.2, R27.1, U12.4
unnamed: U6.16, U8.3
unnamed: U6.18, U8.6
unnamed: U6.19, U8.10
unnamed: U6.20, U8.8
unnamed: U6.21, U8.13
unnamed: U6.22, U8.11
unnamed: U10.21, U10.24
unnamed: U9.116, U10.104
PIF_ADR: U6.11, U9.4
PIF_CLK: U6.9, U9.5
PIF_DAT: U6.13, U9.3
RXCLK: P1.9, U9.146
SDAT: DAUD1.3, U9.7
SRGB0: DVO1.10, U9.25
SRGB1: DVO1.9, U9.24
SRGB2: DVO1.8, U9.23
SRGB3: DVO1.7, U9.20
SRGB4: DVO1.6, U9.19
SRGB5: DVO1.5, U9.18
SRGB6: DVO1.4, U9.15
TXCLK: P1.8, U9.144
VCLK: R28.1, U7.1, U9.11
VREF: CVR1.1, CVR2.1, P1.5, P1.20, U9.135
VTERM: C37.1, C73.1, CVT1.1, CVT2.1, P1.16, P1.17, R24.1, R26.1, U12.3

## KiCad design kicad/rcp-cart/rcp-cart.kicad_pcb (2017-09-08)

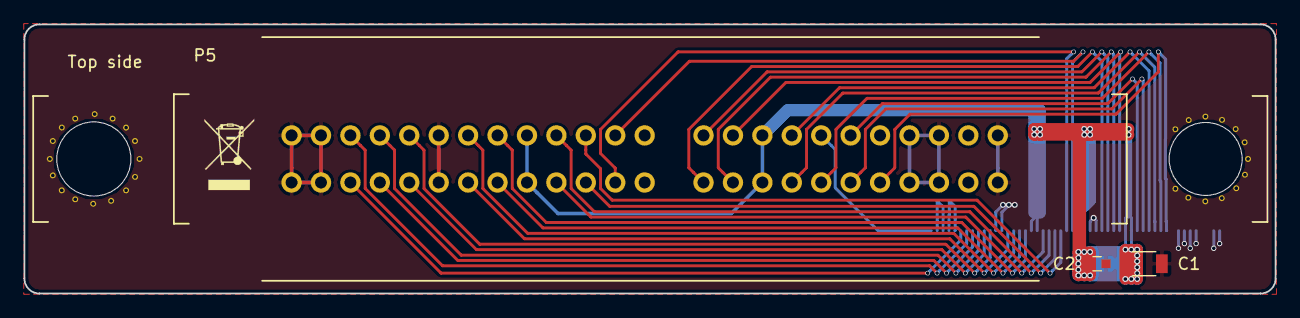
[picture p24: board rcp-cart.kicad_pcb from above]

Board: 2 copper layers, 106.3 x 22.9 mm, 4 parts (1 on the bottom side), 29 nets.

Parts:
C1: 4.7uF; C_1206
C2: .1uF; C_0603
P5: CART-EDGE; cart-edge-2x25-2.54mm
TO MAIN BOARD: 502790-5091; connector-molex-502790-5091

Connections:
+3V3: C1.1, C2.1, P5.9, P5.17, P5.34, P5.42, TO MAIN BOARD.16, TO MAIN BOARD.17, TO MAIN BOARD.24, TO MAIN BOARD.25, TO MAIN BOARD.32, TO MAIN BOARD.33
//CART_READ: P5.10, TO MAIN BOARD.31
//CART_WRITE: P5.8, TO MAIN BOARD.35
//COLDRESET: P5.20, TO MAIN BOARD.14
//NMI: P5.45, TO MAIN BOARD.15
/CART_ADDR00: P5.28, TO MAIN BOARD.44
/CART_ADDR01: P5.29, TO MAIN BOARD.42
/CART_ADDR02: P5.30, TO MAIN BOARD.40
/CART_ADDR03: P5.32, TO MAIN BOARD.36
/CART_ADDR04: P5.36, TO MAIN BOARD.28
/CART_ADDR05: P5.37, TO MAIN BOARD.26
/CART_ADDR06: P5.40, TO MAIN BOARD.20
/CART_ADDR07: P5.41, TO MAIN BOARD.18
/CART_ADDR08: P5.16, TO MAIN BOARD.19
/CART_ADDR09: P5.15, TO MAIN BOARD.21
/CART_ADDR10: P5.12, TO MAIN BOARD.27
/CART_ADDR11: P5.11, TO MAIN BOARD.29
/CART_ADDR12: P5.7, TO MAIN BOARD.37
/CART_ADDR13: P5.5, TO MAIN BOARD.41
/CART_ADDR14: P5.4, TO MAIN BOARD.43
/CART_ADDR15: P5.3, TO MAIN BOARD.45
/CART_ALE_H: P5.35, TO MAIN BOARD.30
/CART_ALE_L: P5.33, TO MAIN BOARD.34
/CIC_CLK: P5.19, TO MAIN BOARD.11
/EEPROM_DAT: P5.21, TO MAIN BOARD.10
/JTCK: P5.44, TO MAIN BOARD.50
/PIF_CIC_DAT_IN: P5.43, TO MAIN BOARD.13
/PIF_CIC_DAT_OUT: P5.18, TO MAIN BOARD.12
GND: C1.2, C2.2, P5.1, P5.2, P5.6, P5.22, P5.23, P5.25, P5.26, P5.27, P5.31, P5.47, P5.48, P5.50, TO MAIN BOARD.1, TO MAIN BOARD.2, TO MAIN BOARD.5, TO MAIN BOARD.6, TO MAIN BOARD.7, TO MAIN BOARD.8, TO MAIN BOARD.22, TO MAIN BOARD.23, TO MAIN BOARD.38, TO MAIN BOARD.39, TO MAIN BOARD.46, TO MAIN BOARD.47, TO MAIN BOARD.48, TO MAIN BOARD.49

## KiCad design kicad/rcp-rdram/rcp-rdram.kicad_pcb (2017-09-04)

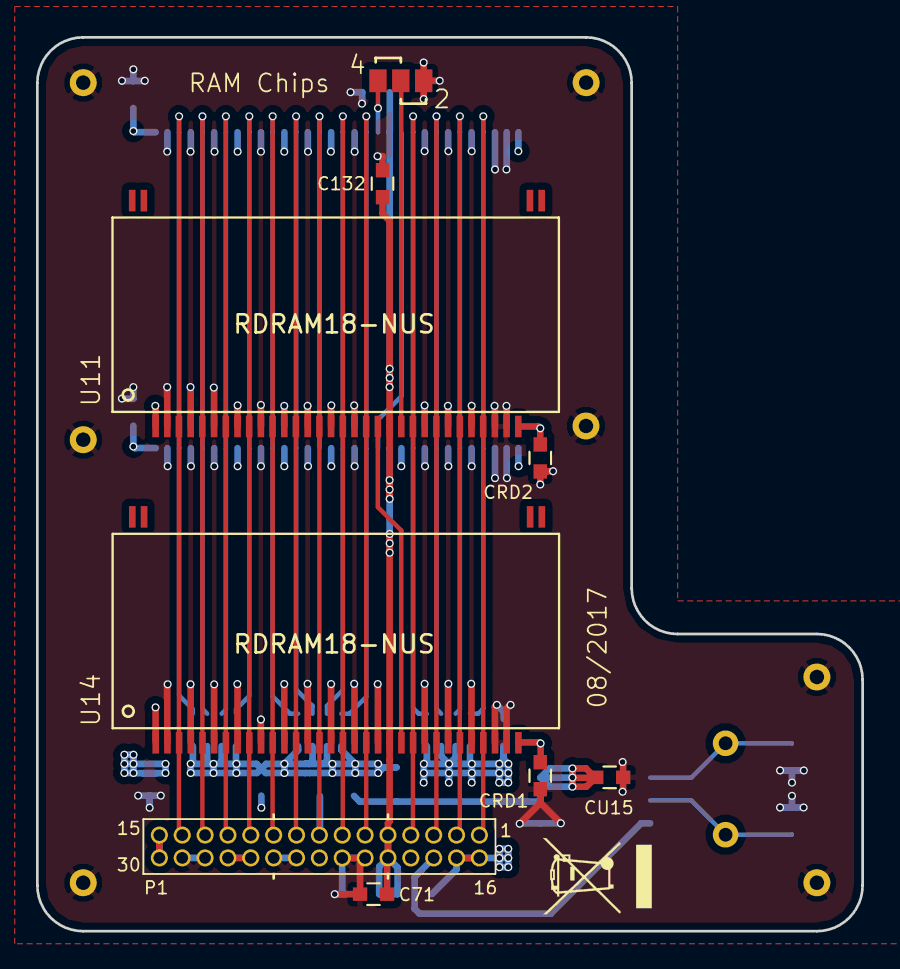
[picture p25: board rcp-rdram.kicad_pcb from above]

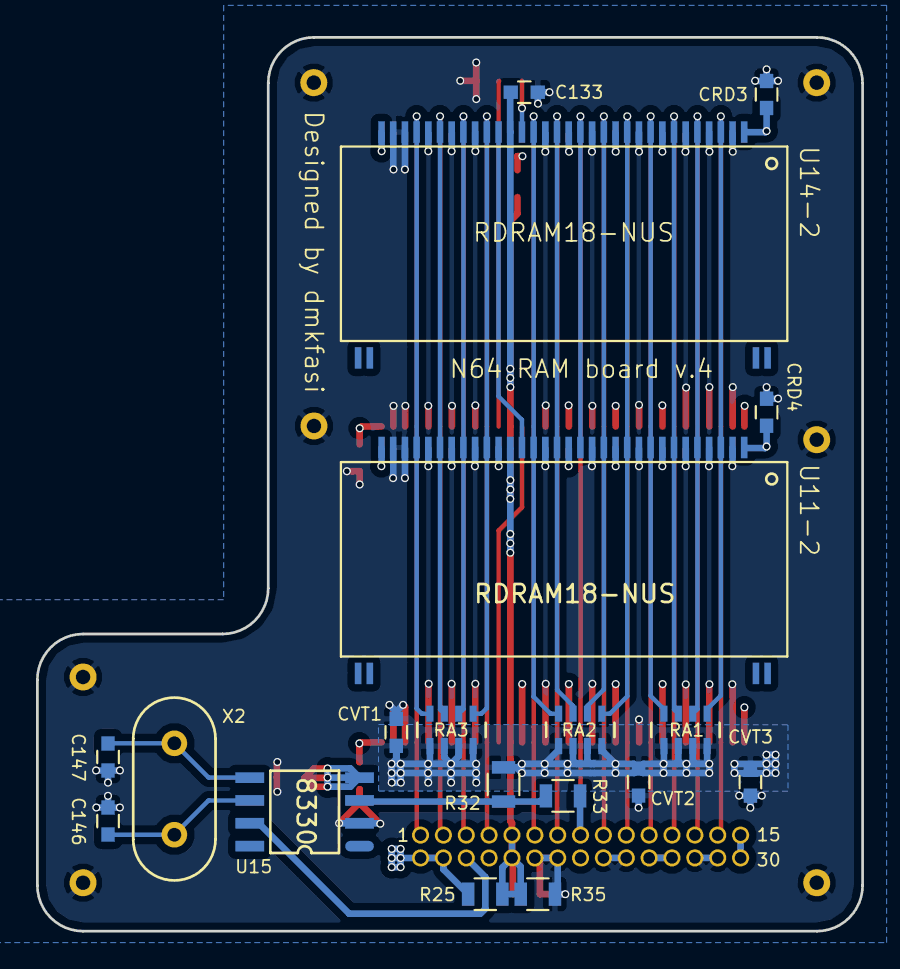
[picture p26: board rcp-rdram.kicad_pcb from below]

Board: 4 copper layers, 45.8 x 49.7 mm, 28 parts (19 on the bottom side), 25 nets.

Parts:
C71, C132, C133: C; C_0603
C146, C147: 40pF; C_0603
CRD1, CRD2, CRD3, CRD4: .1uF; C_0603
CU15: .1uF; C_0603
CVT1, CVT2, CVT3: .1uF; C_0603
JP1: 2/4MB RAM; SolderPoint_3P
P1: RDRAM-EDGE; rdram-edge
R25: 130R; R_0805
R32: 150R; R_0805
R33: 33R; R_0805
R35: 390R; R_0805
RA1, RA2, RA3: 51R; cay16-510-j4
U11, U11-2, U14, U14-2: RDRAM18-NUS; rambus-shp-32
U15: 8330; mx8330-sop-8
X2: 14.705MHz; Crystal_HC-49V

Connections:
+3V3: CRD1.1, CRD2.1, CRD3.1, CRD4.1, CU15.2, P1.15, P1.19, P1.23, P1.26, P1.27, P1.30, U11.1, U11.8, U11.12, U11.16, U11.32, U11-2.1, U11-2.8, U11-2.12, U11-2.16, U11-2.32, U14.1, U14.8, U14.12, U14.16, U14.20, U14.32, U14-2.1, U14-2.8, U14-2.12, U14-2.16, U14-2.32, U15.4
/ADDRESS: P1.12, RA1.3, U11.7, U11-2.7, U14.7, U14-2.7
/COMMAND: P1.6, RA2.4, U11.19, U11-2.19, U14.19, U14-2.19
/DQ0: P1.1, RA3.4, U11.29, U11-2.29, U14.29, U14-2.29
/DQ1: P1.2, RA3.3, U11.27, U11-2.27, U14.27, U14-2.27
/DQ2: P1.3, RA3.2, U11.25, U11-2.25, U14.25, U14-2.25
/DQ3: P1.4, RA3.1, U11.23, U11-2.23, U14.23, U14-2.23
/DQ4: P1.7, RA2.3, U11.17, U11-2.17, U14.17, U14-2.17
/DQ5: P1.10, RA2.1, U11.11, U11-2.11, U14.11, U14-2.11
/DQ6: P1.11, RA1.4, U11.9, U11-2.9, U14.9, U14-2.9
/DQ7: P1.13, RA1.2, U11.5, U11-2.5, U14.5, U14-2.5
/DQ8: P1.14, RA1.1, U11.3, U11-2.3, U14.3, U14-2.3
/ENABLE: P1.18, U15.7
/RXCLK: P1.9, RA2.2, U11.13, U11-2.13, U14.13, U14-2.13
/TXCLK: P1.8, R33.1, U11.15, U11-2.15, U14.15, U14-2.15
/VREF: C71.1, C132.1, C133.1, P1.5, P1.20, R25.2, R35.1, U11.21, U11-2.21, U14.21, U14-2.21
/VTERM: CVT1.2, CVT2.2, CVT3.2, P1.16, P1.17, R25.1, R32.2, RA1.5, RA1.6, RA1.7, RA1.8, RA2.5, RA2.6, RA2.7, RA2.8, RA3.5, RA3.6, RA3.7, RA3.8
GND: C71.2, C132.2, C133.2, C146.2, C147.2, CRD1.2, CRD2.2, CRD3.2, CRD4.2, CU15.1, CVT1.1, CVT2.1, CVT3.1, JP1.3, P1.21, P1.22, P1.24, P1.25, P1.28, P1.29, R35.2, U11.2, U11.4, U11.6, U11.10, U11.14, U11.18, U11.24, U11.26, U11.28, U11.30, U11.31, U11-2.2, U11-2.4, U11-2.6, U11-2.10, U11-2.14, U11-2.18, U11-2.22, U11-2.24, U11-2.26, U11-2.28, U11-2.30, U11-2.31, U14.2, U14.4, U14.6, U14.10, U14.14, U14.18, U14.24, U14.26, U14.28, U14.30, U14.31, U14-2.2, U14-2.4, U14-2.6, U14-2.10, U14-2.14, U14-2.18, U14-2.24, U14-2.26, U14-2.28, U14-2.30, U14-2.31, U15.2
unnamed: C146.1, U15.6, X2.2
unnamed: C147.1, U15.5, X2.1
unnamed: JP1.1, U14-2.20
unnamed: JP1.2, U11.22
unnamed: R32.1, R33.2, U15.3
unnamed: U11-2.20, U14-2.22
unnamed: U11.20, U14.22

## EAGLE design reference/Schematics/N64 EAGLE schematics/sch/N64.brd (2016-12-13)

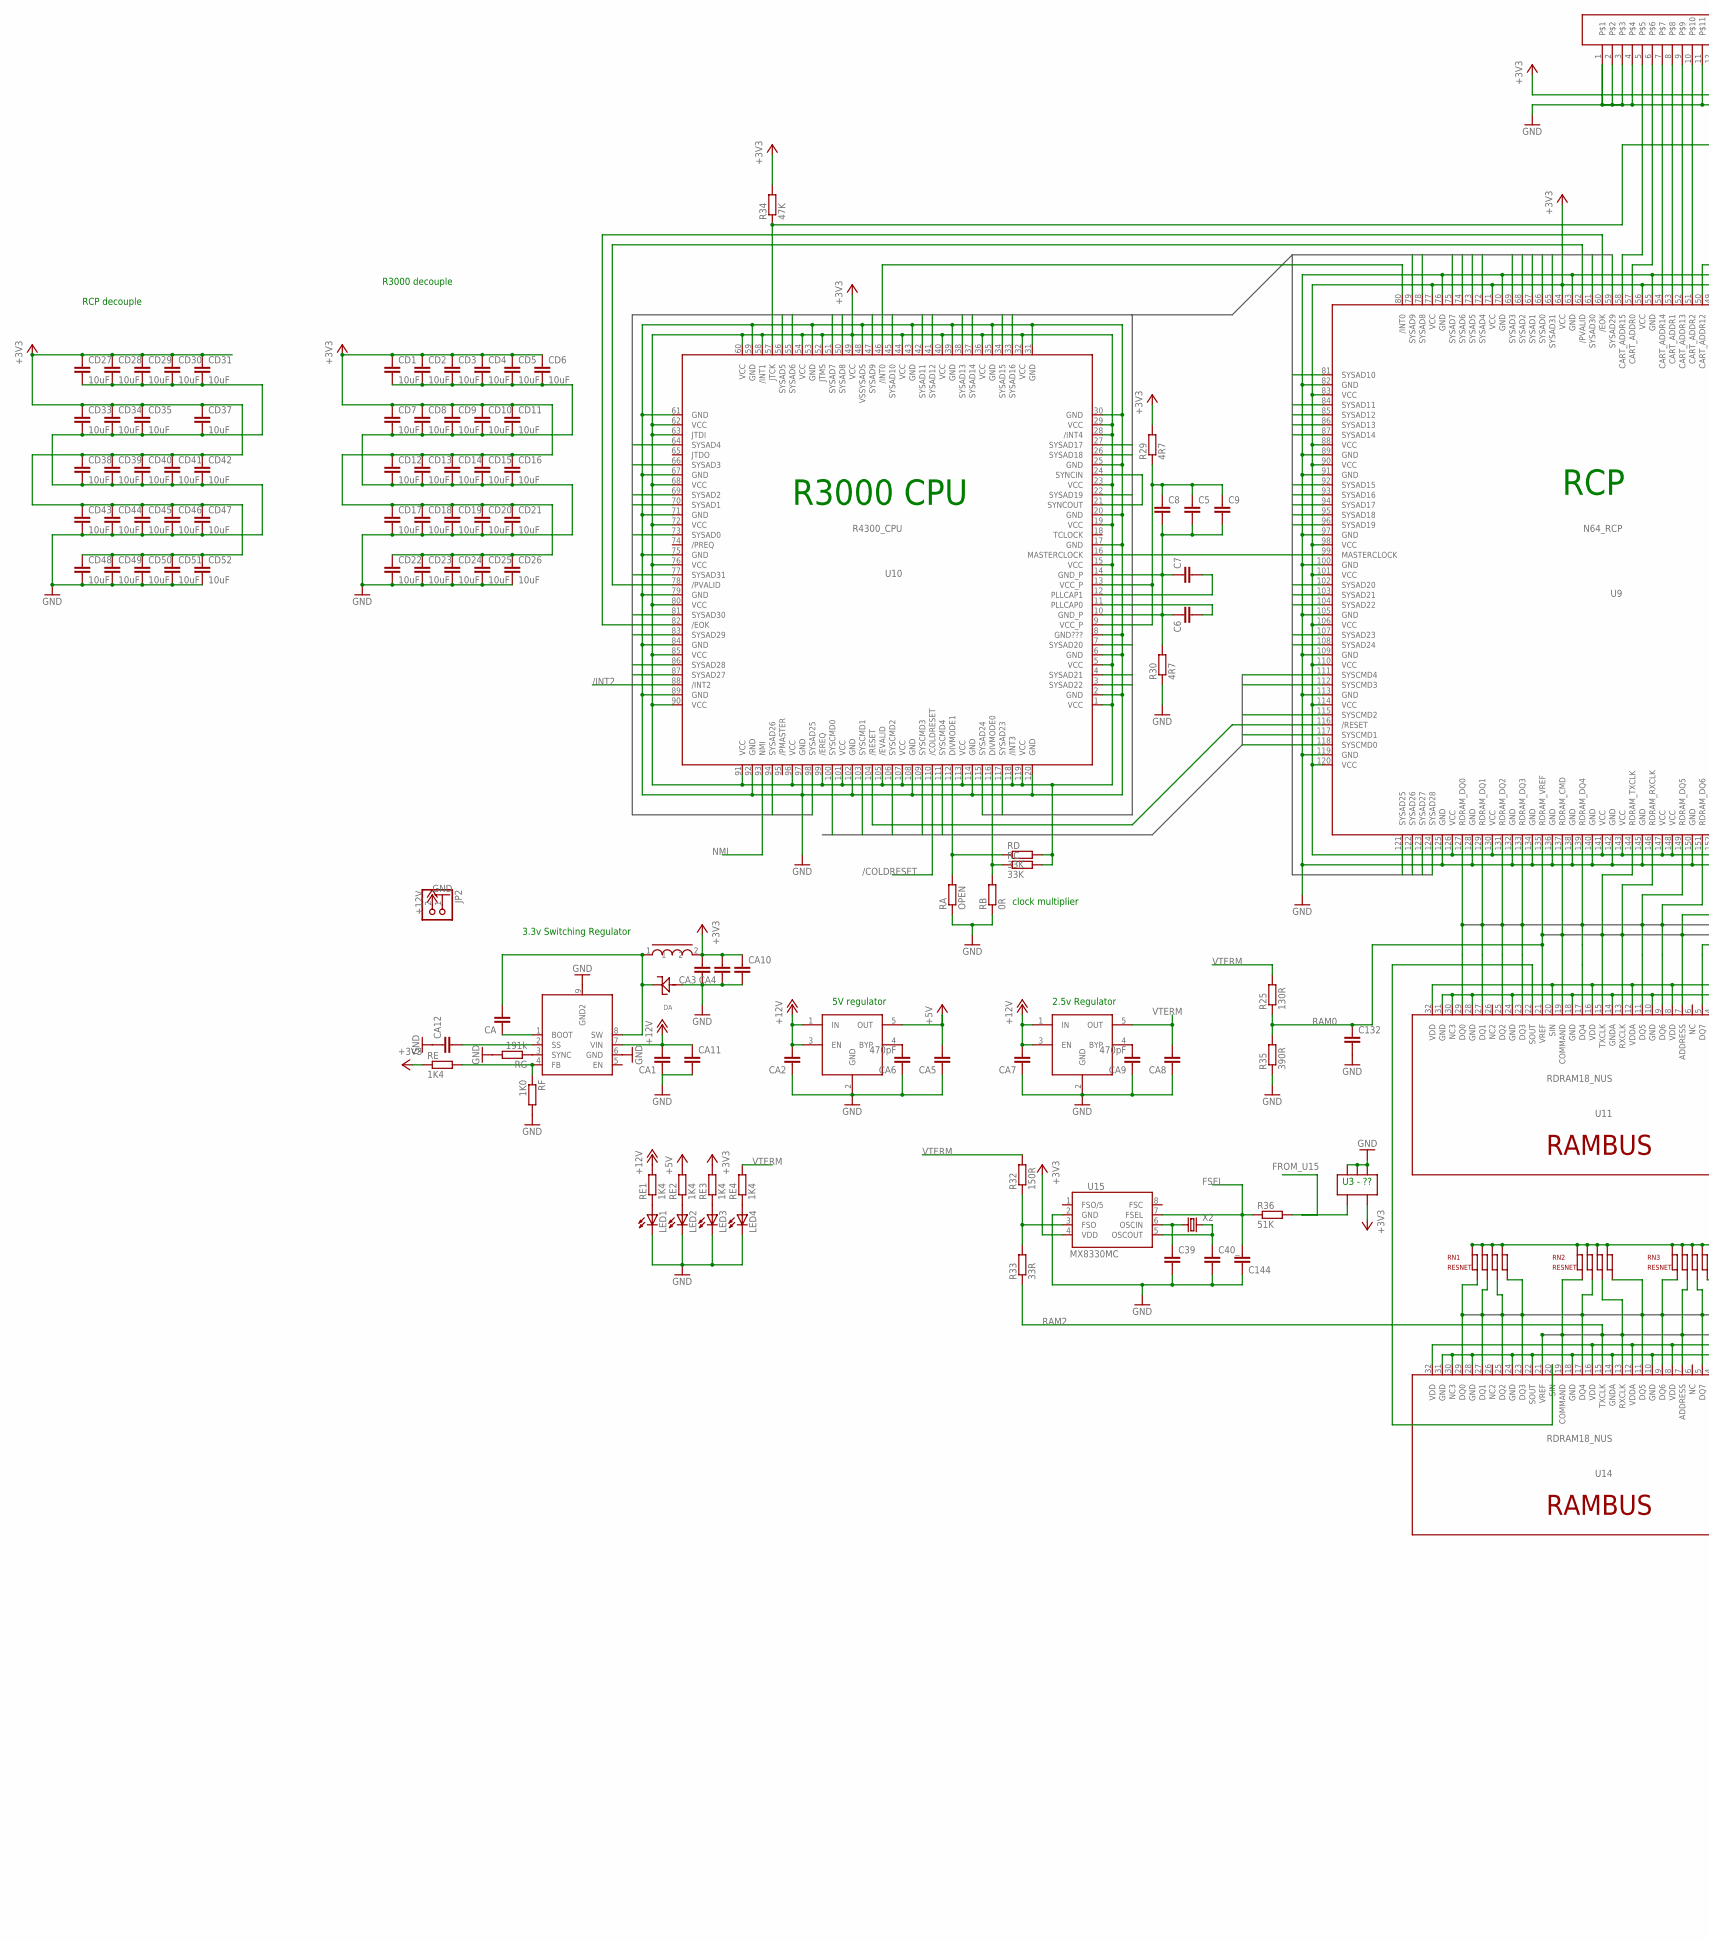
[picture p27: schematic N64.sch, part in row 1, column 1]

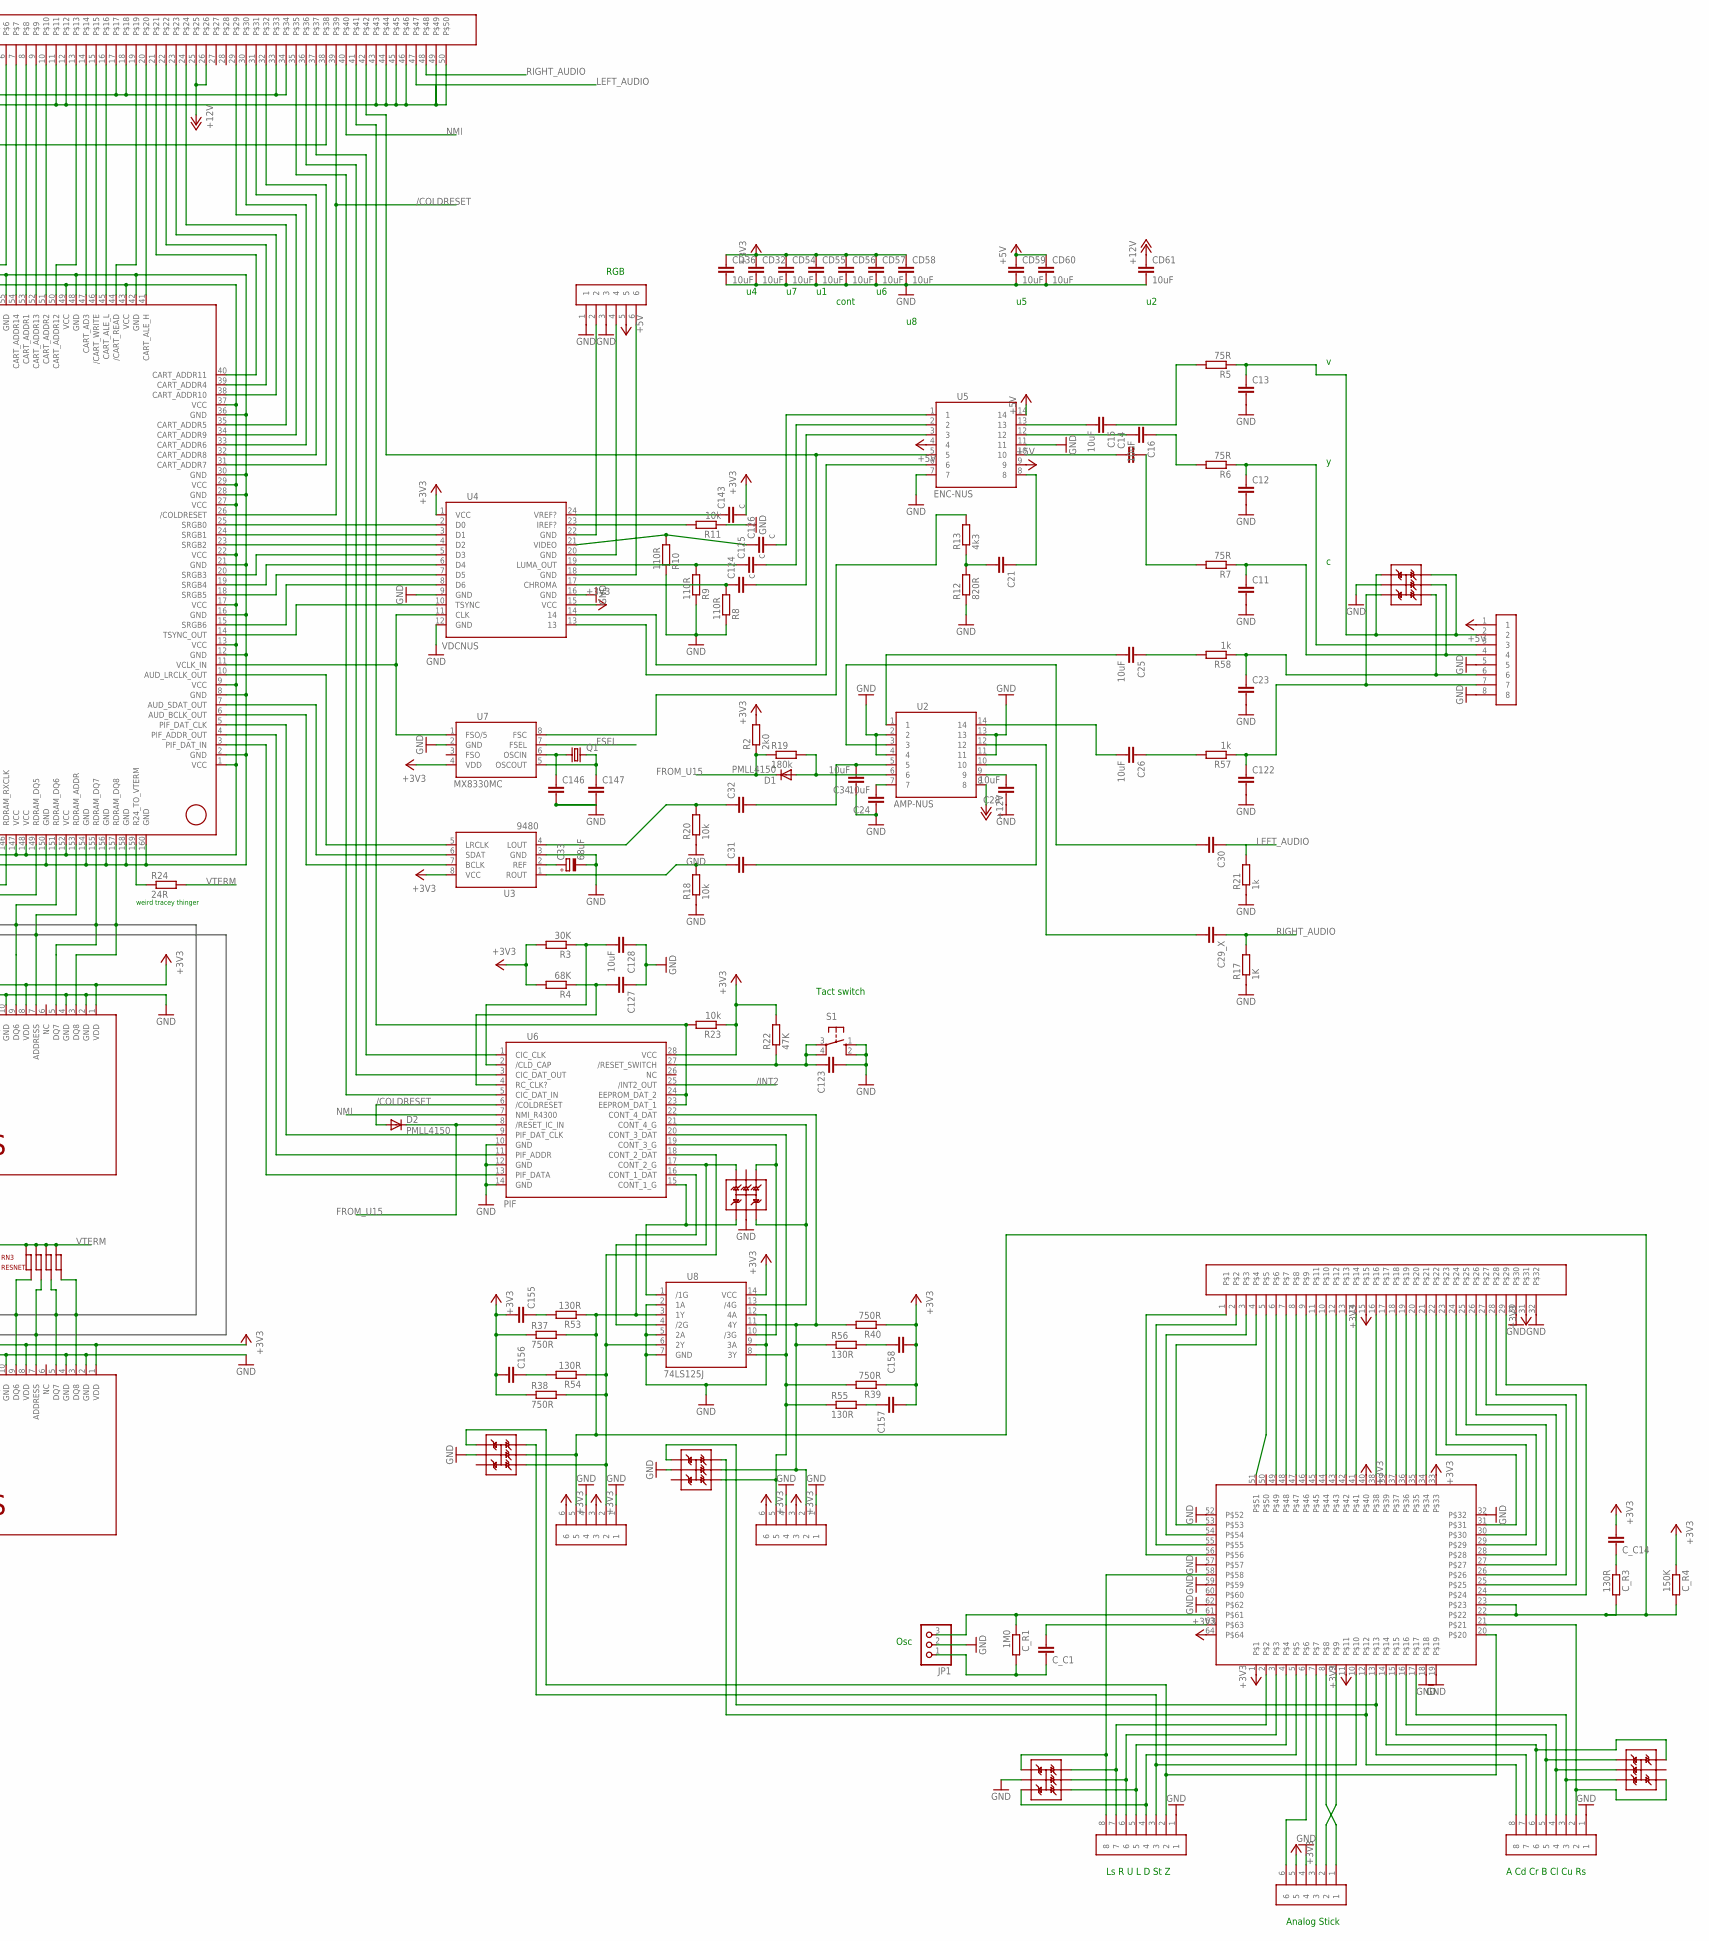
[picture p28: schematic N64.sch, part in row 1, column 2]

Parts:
3V3: LM22680; PSOP-8
AV: PINHEAD-1X8; 2MMPINHEAD-1X8
BUTT1, BUTT2: PINHEAD-1X8; 2MMPINHEAD-1X8
C5: C-EUC0805K; C0805K
C6, C7, C8, C9, C11, C12, C13, C14, C21, C23, C29_X, C30, C31, C32, C39, C40_, C122, C123, C127, C132, C144, C146, C147, C155, C156, C157, C158: C-EUC0805; C0805
C15, C16, C24, C25, C26, C28, C34, C128: 10uF; C0805
C33: 68uF; C/6032-28R
C124, C125, C126, C143: c; C0805
CA, CA1, CA4: C-EUC1206K; C1206K
CA2, CA5, CA7, CA8, CA10, CA11, CA12: C-EUC0805K; C0805K
CA3: C-EUC1210K; C1210K
CA6, CA9: 470pF; C0805K
CD1, CD2, CD3, CD4, CD5, CD6, CD7, CD8, CD9, CD10, CD11, CD12, CD13, CD14, CD15, CD16, CD17, CD18, CD19, CD20, CD21, CD22, CD23, CD24, CD25, CD26, CD27, CD28, CD29, CD30, CD31, CD32, CD33, CD34, CD35, CD36, CD37, CD38, CD39, CD40, CD41, CD42, CD43, CD44, CD45, CD46, CD47, CD48, CD49, CD50, CD51, CD52, CD54, CD55, CD56, CD57, CD58, CD59, CD60, CD61: 10uF; C0805
CONT1, CONT2: PINHEAD-1X6; 2MMPINHEAD-1X6
C_C1, C_C14: C-EUC0805; C0805
C_R1: 1M0; M0805
C_R3: 130R; M0805
C_R4: 150K; M0805
C_U1: CNT-NUS; PQFP64
D1, D2: PMLL4150; SOD80C
DA: STKYDIODE
JOY: PINHEAD-1X6; 2MMPINHEAD-1X6
JP1: PINHD-1X3; 1X03
JP2: PINHD-1X2; 1X02
LED1, LED2, LED3, LED4: LEDCHIPLED_0805; CHIPLED_0805
Q1: CRYTALHC49S; HC49/S
R2: 2k0; M0805
R3: 30K; M0805
R4: 68K; M0805
R5, R6, R7: 75R; M0805
R8, R9, R10: 110R; M0805
R11, R18, R20, R23: 10k; M0805
R12: 820R; M0805
R13: 4k3; M0805
R17: 1K; M0805
R19: 180k; M0805
R21, R57, R58: 1k; M0805
R22, R34: 47K; M0805
R24: 24R; M0805
R25, R53, R54, R55, R56: 130R; M0805
R29, R30: 4R7; M0805
R32: 150R; M0805
R33: 33R; M0805
R35: 390R; M0805
R36: 51K; M0805
R37, R38, R39, R40: 750R; M0805
RA: OPEN; M0805
RB: 0R; M0805
RC: 33K; M0805
RD: 33K; M0805
RE, RE1, RE2, RE3, RE4: 1K4; M0805
RF: 1K0; M0805
RG: 191k; M0805
RGB: PINHEAD-1X6; 2MMPINHEAD-1X6
RN1, RN2, RN3: RESNET; RESARRAY
S1: 10-XX; B3F-10XX
TVS1, TVS2, TVS3, TVS4, TVS5, TVS6: TVS; SC-74
U2: AMP-NUS; SO14
U3: 9480; SO8
U3_: U3; SOT23-5
U4: VDCNUS; SO24
U5: ENC-NUS; SO14
U6: PIF; SO28W
U7, U15: MX8330MC; SO08
U8: 74LS125J; QSOP14
U9: N64_RCP; PQFP160
U10: R4300_CPU; QFP120
U11, U14: RDRAM18_NUS; SHP32
U12, U13: MIC5219; SOT23-5
U$37: PINHEAD-25X2
U$38: PINHEAD-16X2SMALLER; 2MMPINHEAD-16X2
U$52: INDUCTOR
X2: CRYTALHC49S; HC49/S

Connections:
3V3: C143.2, C155.2, C156.2, C157.2, C158.2, CA3.2, CA4.2, CA10.1, CD1.1, CD2.1, CD3.1, CD4.1, CD5.1, CD6.1, CD7.1, CD8.1, CD9.1, CD10.1, CD11.1, CD12.1, CD13.1, CD14.1, CD15.1, CD16.1, CD17.1, CD18.1, CD19.1, CD20.1, CD21.1, CD22.1, CD23.1, CD24.1, CD25.1, CD26.1, CD27.1, CD28.1, CD29.1, CD30.1, CD31.1, CD32.1, CD33.1, CD34.1, CD35.1, CD36.1, CD37.1, CD38.1, CD39.1, CD40.1, CD41.1, CD42.1, CD43.1, CD44.1, CD45.1, CD46.1, CD47.1, CD48.1, CD49.1, CD50.1, CD51.1, CD52.1, CD54.1, CD55.1, CD56.1, CD57.1, CD58.1, CONT1.3, CONT1.6, CONT2.3, CONT2.6, C_C14.2, C_R4.1, C_U1.1, C_U1.11, C_U1.33, C_U1.40, C_U1.64, JOY.5, R2.2, R3.2, R4.2, R22.2, R23.1, R29.2, R34.2, R37.1, R38.1, R39.1, R40.1, RC.2, RD.2, RE.1, RE3.2, U3.8 (VCC), U3_.5, U4.1 (VCC), U4.15 (VCC), U6.28 (VCC), U7.4 (VDD), U8.14 (VCC), U9.1 (VCC), U9.9 (VCC), U9.13 (VCC), U9.17 (VCC), U9.22 (VCC), U9.27 (VCC), U9.29 (VCC), U9.37 (VCC), U9.43 (VCC), U9.49 (VCC), U9.56 (VCC), U9.64 (VCC), U9.71 (VCC), U9.77 (VCC), U9.83 (VCC), U9.88 (VCC), U9.90 (VCC), U9.98 (VCC), U9.101 (VCC), U9.106 (VCC), U9.110 (VCC), U9.114 (VCC), U9.120 (VCC), U9.126 (VCC), U9.130 (VCC), U9.141 (VCC), U9.143 (VCC), U9.147 (VCC), U9.148 (VCC), U9.152 (VCC), U10.1 (VCC), U10.5 (VCC), U10.15 (VCC), U10.19 (VCC), U10.23 (VCC), U10.28 (/INT4), U10.29 (VCC), U10.32 (VCC), U10.36 (VCC), U10.40 (VCC), U10.44 (VCC), U10.49 (VCC), U10.52 (JTMS), U10.54 (VCC), U10.58 (/INT1), U10.60 (VCC), U10.62 (VCC), U10.63 (JTDI), U10.68 (VCC), U10.72 (VCC), U10.76 (VCC), U10.80 (VCC), U10.85 (VCC), U10.90 (VCC), U10.91 (VCC), U10.96 (VCC), U10.99 (/EREQ), U10.101 (VCC), U10.105 (/EVALID), U10.107 (VCC), U10.113 (VCC), U10.118 (/INT3), U10.119 (VCC), U11.1 (VDD), U11.8 (VDD), U11.12 (VDDA), U11.16 (VDD), U11.20 (SIN), U11.32 (VDD), U14.1 (VDD), U14.8 (VDD), U14.12 (VDDA), U14.16 (VDD), U14.32 (VDD), U15.4 (VDD), U$37.17, U$37.18, U$37.33, U$37.34, U$38.15, U$38.31, U$52.2
+5V: AV.1, CA5.2, CD59.1, CD60.1, RE2.2, RGB.5, U5.4, U5.9, U5.14, U13.5 (OUT)
+12V: 3V3.7 (VIN), CA1.2, CA2.2, CA7.2, CA11.1, CD61.1, JP2.2, RE1.2, U2.8, U12.1 (IN), U12.3 (EN), U13.1 (IN), U13.3 (EN), U$37.25, U$37.26
/COLDRESET: D2.A, U6.6 (/COLDRESET), U9.26 (/COLDRESET), U10.110 (/COLDRESET), U$37.39
/INT2: U6.25 (/INT2_OUT), U10.88 (/INT2)
ADJ: 3V3.4 (FB), RE.2, RF.1
C16X: C16.1, R6.2
C_C11: C_C1.1, C_R1.2, JP1.1
DQ0: RN1.1, U9.127 (RDRAM_DQ0), U11.29 (DQ0), U14.29 (DQ0)
DQ1: RN1.2, U9.129 (RDRAM_DQ1), U11.27 (DQ1), U14.27 (DQ1)
DQ2: RN1.3, U9.131 (RDRAM_DQ2), U11.25 (DQ2), U14.25 (DQ2)
DQ3: RN1.4, U9.133 (RDRAM_DQ3), U11.23 (DQ3), U14.23 (DQ3)
DQ4: RN2.2, U9.139 (RDRAM_DQ4), U11.17 (DQ4), U14.17 (DQ4)
DQ5: RN2.4, U9.149 (RDRAM_DQ5), U11.11 (DQ5), U14.11 (DQ5)
DQ6: RN3.1, U9.151 (RDRAM_DQ6), U11.9 (DQ6), U14.9 (DQ6)
DQ7: RN3.3, U9.155 (RDRAM_DQ7), U11.5 (DQ7), U14.5 (DQ7)
DQ8: RN3.4, U9.157 (RDRAM_DQ8), U11.3 (DQ8), U14.3 (DQ8)
FROM_U15: D1.C, D2.C, R2.1, R19.1, R36.2, U3_.4, U6.8 (/RESET_IC_IN)
FSEL: C144.2, R36.1, U7.7 (FSEL), U15.7 (FSEL)
FSO1: R32.1, R33.2, U15.3 (FSO)
GND: 3V3.6 (GND), 3V3.9 (GND2), AV.5, AV.8, BUTT1.1, BUTT2.1, C11.2, C12.2, C13.2, C23.2, C24.1, C28.1, C33.-, C34.1, C39.2, C40_.2, C122.2, C123.2, C127.1, C128.1, C132.2, C144.1, C146.2, C147.2, CA1.1, CA2.1, CA3.1, CA4.1, CA5.1, CA6.1, CA7.1, CA8.1, CA9.1, CA10.2, CA11.2, CA12.1, CD1.2, CD2.2, CD3.2, CD4.2, CD5.2, CD6.2, CD7.2, CD8.2, CD9.2, CD10.2, CD11.2, CD12.2, CD13.2, CD14.2, CD15.2, CD16.2, CD17.2, CD18.2, CD19.2, CD20.2, CD21.2, CD22.2, CD23.2, CD24.2, CD25.2, CD26.2, CD27.2, CD28.2, CD29.2, CD30.2, CD31.2, CD32.2, CD33.2, CD34.2, CD35.2, CD36.2, CD37.2, CD38.2, CD39.2, CD40.2, CD41.2, CD42.2, CD43.2, CD44.2, CD45.2, CD46.2, CD47.2, CD48.2, CD49.2, CD50.2, CD51.2, CD52.2, CD54.2, CD55.2, CD56.2, CD57.2, CD58.2, CD59.2, CD60.2, CD61.2, CONT1.1, CONT1.4, CONT2.1, CONT2.4, C_U1.18, C_U1.19, C_U1.32, C_U1.52, C_U1.57, C_U1.59, C_U1.62, DA.+, JOY.4, JP1.2, JP2.1, LED1.C, LED2.C, LED3.C, LED4.C, R8.1, R9.1, R10.1, R11.1, R12.1, R17.1, R18.1, R20.1, R21.1, R30.1, R35.1, RA.1, RB.1, RF.2, RG.2, RGB.1, RGB.3, S1.1 (S), S1.2 (S1), TVS1.2, TVS2.2, TVS3.2, TVS4.2, TVS5.2, U2.2, U2.4, U2.11, U2.13, U3.3 (GND), U3_.1, U3_.2, U3_.3, U4.9 (GND), U4.12 (GND), U4.16 (GND), U5.7, U5.11, U6.10 (GND), U6.12 (GND), U6.14 (GND), U7.2 (GND), U8.2 (1A), U8.5 (2A), U8.7 (GND), U8.9 (3A), U8.12 (4A), U9.2 (GND), U9.8 (GND), U9.12 (GND), U9.16 (GND), U9.21 (GND), U9.28 (GND), U9.30 (GND), U9.36 (GND), U9.42 (GND), U9.48 (GND), U9.55 (GND), U9.63 (GND), U9.70 (GND), U9.76 (GND), U9.82 (GND), U9.89 (GND), U9.91 (GND), U9.97 (GND), U9.100 (GND), U9.105 (GND), U9.109 (GND), U9.113 (GND), U9.119 (GND), U9.125 (GND), U9.128 (GND), U9.132 (GND), U9.134 (GND), U9.136 (GND), U9.138 (GND), U9.140 (GND), U9.142 (GND), U9.145 (GND), U9.150 (GND), U9.154 (GND), U9.156 (GND), U9.158 (GND), U9.160 (GND), U10.2 (GND), U10.6 (GND), U10.8 (GND???), U10.17 (GND), U10.20 (GND), U10.25 (GND), U10.30 (GND), U10.31 (GND), U10.35 (GND), U10.39 (GND), U10.43 (GND), U10.48 (VSSYSADS), U10.53 (GND), U10.59 (GND), U10.61 (GND), U10.67 (GND), U10.71 (GND), U10.75 (GND), U10.79 (GND), U10.84 (GND), U10.89 (GND), U10.92 (GND), U10.97 (GND), U10.102 (GND), U10.108 (GND), U10.114 (GND), U10.120 (GND), U11.2 (GND), U11.4 (GND), U11.10 (GND), U11.14 (GNDA), U11.18 (GND), U11.24 (GND), U11.28 (GND), U11.30 (NC3), U11.31 (GND), U12.2 (GND), U13.2 (GND), U14.2 (GND), U14.4 (GND), U14.10 (GND), U14.14 (GNDA), U14.18 (GND), U14.22 (SOUT), U14.24 (GND), U14.28 (GND), U14.30 (NC3), U14.31 (GND), U15.2 (GND), U$37.1, U$37.2, U$37.3, U$37.4, U$37.11, U$37.12, U$37.43, U$37.44, U$37.45, U$37.46, U$37.49, U$37.50, U$38.30, U$38.32
INT0: U9.80 (/INT0), U10.46 (/INT0)
LEFT_AUDIO: C30.1, R21.2, U$37.47
unnamed: C156.1, R54.2
unnamed: C155.1, R53.2
unnamed: U4.11 (CLK), U7.1 (FSO/5), U9.11 (VCLK_IN)
unnamed: R24.1, U9.159 (R24_TO_VTERM)
unnamed: C147.1, Q1.2, U7.5 (OSCOUT)
unnamed: C146.1, Q1.1, U7.6 (OSCIN)
unnamed: BUTT1.2, C_U1.20, TVS3.1
unnamed: RGB.2, U4.22 (GND)
unnamed: RGB.4, U4.20 (GND)
unnamed: U6.9 (PIF_DAT_CLK), U9.5 (PIF_DAT_CLK)
unnamed: U6.11 (PIF_ADDR), U9.4 (PIF_ADDR_OUT)
unnamed: U6.13 (PIF_DATA), U9.3 (PIF_DAT_IN)
unnamed: TVS2.1, U6.15 (CONT_1_G), U8.1 (/1G)
unnamed: CONT1.5, C_R3.2, C_R4.2, C_U1.22, C_U1.23, R37.2, R53.1, TVS3.5, U6.16 (CONT_1_DAT), U8.3 (1Y)
unnamed: BUTT1.3, C_U1.10, TVS3.6
unnamed: LED1.A, RE1.1
unnamed: CONT1.2, R38.2, R54.1, TVS3.4, U6.18 (CONT_2_DAT), U8.6 (2Y)
unnamed: TVS2.4, U6.19 (CONT_3_G), U8.10 (/3G)
unnamed: CONT2.5, R39.2, R55.1, TVS4.4, U6.20 (CONT_3_DAT), U8.8 (3Y)
unnamed: TVS2.3, U6.21 (CONT_4_G), U8.13 (/4G)
unnamed: CONT2.2, R40.2, R56.1, TVS4.5, U6.22 (CONT_4_DAT), U8.11 (4Y)
unnamed: U4.2 (D0), U9.25 (SRGB0)
unnamed: U9.116 (/RESET), U10.104 (/RESET)
unnamed: TVS2.6, U6.17 (CONT_2_G), U8.4 (/2G)
unnamed: U9.62 (/PVALID), U10.78 (/PVALID)
unnamed: U9.60 (/EOK), U10.82 (/EOK)
unnamed: C123.1, R22.1, S1.3, S1.4 (P1), U6.27 (/RESET_SWITCH)
unnamed: U4.3 (D1), U9.24 (SRGB1)
unnamed: RB.2, RC.1, U10.116 (DIVMODE0)
unnamed: U9.39 (CART_ADDR4), U$37.22
unnamed: RA.2, RD.1, U10.112 (DIVMODE1)
unnamed: U9.58 (CART_ADDR15), U$37.5
unnamed: U9.57 (CART_ADDR0), U$37.6
unnamed: U9.54 (CART_ADDR14), U$37.7
unnamed: U9.53 (CART_ADDR1), U$37.8
unnamed: U9.52 (CART_ADDR13), U$37.9
unnamed: U9.51 (CART_ADDR2), U$37.10
unnamed: U9.99 (MASTERCLOCK), U10.16 (MASTERCLOCK)
unnamed: U9.50 (CART_ADDR12), U$37.13
unnamed: U9.47 (CART_AD3), U$37.14
unnamed: U9.46 (/CART_WRITE), U$37.15
unnamed: U9.45 (CART_ALE_L), U$37.16
unnamed: U9.44 (/CART_READ), U$37.19
unnamed: U9.41 (CART_ALE_H), U$37.20
unnamed: U9.38 (CART_ADDR10), U$37.23
unnamed: U9.35 (CART_ADDR5), U$37.24
unnamed: U9.34 (CART_ADDR9), U$37.29
unnamed: U9.33 (CART_ADDR6), U$37.30
unnamed: U9.32 (CART_ADDR8), U$37.31
unnamed: U9.31 (CART_ADDR7), U$37.32
unnamed: C157.1, R55.2
unnamed: U6.5 (CIC_DAT_IN), U$37.35
unnamed: U6.3 (CIC_DAT_OUT), U$37.36
unnamed: U6.1 (CIC_CLK), U$37.37
unnamed: R23.2, U6.23 (EEPROM_DAT_1), U6.24 (EEPROM_DAT_2), U$37.41
unnamed: C5.1, C8.1, C9.1, R29.1, U10.9 (VCC_P), U10.13 (VCC_P)
unnamed: C5.2, C6.1, C7.1, C8.2, C9.2, R30.2, U10.10 (GND_P), U10.14 (GND_P)
unnamed: C6.2, U10.11 (PLLCAP0)
unnamed: C7.2, U10.12 (PLLCAP1)
unnamed: U10.21 (SYNCOUT), U10.24 (SYNCIN)
unnamed: U3.5 (LRCLK), U9.10 (AUD_LRCLK_OUT)
unnamed: U3.6 (SDAT), U9.7 (AUD_SDAT_OUT)
unnamed: U3.7 (BCLK), U9.6 (AUD_BCLK_OUT)
unnamed: C33.+, U3.2 (REF)
unnamed: C127.2, R4.1, U6.4 (RC_CLK?)
unnamed: C128.2, R3.1, U6.2 (/CLD_CAP)
unnamed: U4.4 (D2), U9.23 (SRGB2)
unnamed: U4.5 (D3), U9.20 (SRGB3)
unnamed: U4.6 (D4), U9.19 (SRGB4)
unnamed: U4.7 (D5), U9.18 (SRGB5)
unnamed: U4.8 (D6), U9.15 (SRGB6)
unnamed: U4.10 (TSYNC), U9.14 (TSYNC_OUT)
unnamed: R11.2, U4.23 (IREF?)
unnamed: C126.1, R10.2, U4.21 (VIDEO)
unnamed: R34.1, U10.57 (JTCK), U$37.38
unnamed: C32.1, R20.2, U3.4 (LOUT)
unnamed: C31.1, R18.2, U3.1 (ROUT)
unnamed: C143.1, U4.24 (VREF?)
unnamed: C125.1, R9.2, U4.19 (LUMA_OUT)
unnamed: C124.1, R8.2, U4.17 (CHROMA)
unnamed: C158.1, R56.2
unnamed: C32.2, C34.2, U2.5
unnamed: C31.2, U2.10
unnamed: C24.2, U2.7
unnamed: C28.2, U2.9
unnamed: C29_X.2, U2.12
unnamed: C30.2, U2.3
unnamed: D1.A, R19.2, U2.6
unnamed: C25.1, R58.2
unnamed: C14.1, U5.10
unnamed: C26.2, U2.14
unnamed: AV.7, C122.1, R57.1, TVS1.3
unnamed: C26.1, R57.2
unnamed: C_U1.56, U$38.1
unnamed: CA6.2, U13.4 (BYP)
unnamed: C_U1.55, U$38.2
unnamed: U4.13, U5.6
unnamed: U4.14, U5.5, U$37.42
unnamed: C124.2, U5.3
unnamed: C125.2, U5.2
unnamed: C126.2, U5.1
unnamed: C15.1, R5.2
unnamed: C15.2, U5.13
unnamed: C16.2, U5.12
unnamed: AV.4, C11.1, R7.1, TVS1.5
unnamed: AV.3, C12.1, R6.1
unnamed: C14.2, R7.2
unnamed: C21.1, U5.8
unnamed: R13.2, U7.8 (FSC)
unnamed: C21.2, R12.2, R13.1
unnamed: AV.2, C13.1, R5.1, TVS1.1, TVS1.6
unnamed: RGB.6, U4.18 (GND)
unnamed: C_U1.8, JOY.1
unnamed: C_U1.54, U$38.3
unnamed: C_U1.53, U$38.4
unnamed: C_U1.9, JOY.2
unnamed: C_U1.51, U$38.5
unnamed: C_U1.49, U$38.6
unnamed: C_U1.48, U$38.7
unnamed: C_U1.47, U$38.8
unnamed: U9.40 (CART_ADDR11), U$37.21
unnamed: C_U1.46, U$38.9
unnamed: C_U1.45, U$38.11
unnamed: C_U1.44, U$38.10
unnamed: C_U1.43, U$38.12
unnamed: C_U1.42, U$38.13
unnamed: C_U1.41, U$38.14
unnamed: BUTT2.2, C_U1.21, TVS6.1
unnamed: C_U1.38, U$38.16
unnamed: C_U1.37, U$38.18
unnamed: C_U1.39, U$38.17
unnamed: C_U1.36, U$38.19
unnamed: C_U1.35, U$38.20
unnamed: C_U1.34, U$38.21
unnamed: C_U1.31, U$38.22
unnamed: C_U1.30, U$38.23
unnamed: C_U1.29, U$38.24
unnamed: C_U1.28, U$38.25
unnamed: C_U1.27, U$38.26
unnamed: C_U1.26, U$38.27
unnamed: C_U1.25, U$38.28
unnamed: C_U1.24, U$38.29
unnamed: C_C14.1, C_R3.1
unnamed: 3V3.2 (SS), CA12.2
unnamed: BUTT2.3, C_U1.17, TVS6.6
unnamed: BUTT2.4, C_U1.16, TVS6.5
unnamed: BUTT2.5, C_U1.15, TVS6.4
unnamed: BUTT2.6, C_U1.14, TVS6.3
unnamed: BUTT2.7, C_U1.13, TVS4.1
unnamed: BUTT2.8, C_U1.12, TVS4.6
unnamed: C_U1.7, JOY.3
unnamed: C_U1.6, JOY.6
unnamed: BUTT1.4, C_U1.5, TVS5.3
unnamed: BUTT1.5, C_U1.4, TVS5.4
unnamed: BUTT1.6, C_U1.3, TVS5.5
unnamed: BUTT1.7, C_U1.2, TVS5.6
unnamed: BUTT1.8, C_U1.58, TVS5.1
unnamed: C_R1.1, C_U1.61, JP1.3
unnamed: C_C1.2, C_U1.63
unnamed: CA9.2, U12.4 (BYP)
unnamed: 3V3.3 (SYNC), RG.1
unnamed: 3V3.1 (BOOT), CA.1
unnamed: LED2.A, RE2.1
unnamed: LED4.A, RE4.1
unnamed: LED3.A, RE3.1
NMI: U6.7 (NMI_R4300), U10.93 (NMI), U$37.40
OSCIN1: C39.1, U15.6 (OSCIN), X2.1
OSCOUT1: C40_.1, U15.5 (OSCOUT), X2.2
R58: AV.6, C23.1, R58.1, TVS1.4
RAM0: C132.1, R25.1, R35.2, U9.135 (RDRAM_VREF), U11.21 (VREF), U14.21 (VREF)
RAM1: RN2.1, U9.137 (RDRAM_CMD), U11.19 (COMMAND), U14.19 (COMMAND)
RAM2: R33.1, U9.144 (RDRAM_TXCLK), U11.15 (TXCLK), U14.15 (TXCLK)
RAM3: RN2.3, U9.146 (RDRAM_RXCLK), U11.13 (RXCLK), U14.13 (RXCLK)
RAM4: RN3.2, U9.153 (RDRAM_ADDR), U11.7 (ADDRESS), U14.7 (ADDRESS)
RIGHT_AUDIO: C29_X.1, R17.2, U$37.48
SW: 3V3.8 (SW), CA.2, DA.-, U$52.1
SYSAD0: U9.66 (SYSAD0), U10.73 (SYSAD0)
SYSAD1: U9.67 (SYSAD1), U10.70 (SYSAD1)
SYSAD2: U9.68 (SYSAD2), U10.69 (SYSAD2)
SYSAD3: U9.69 (SYSAD3), U10.66 (SYSAD3)
SYSAD4: U9.72 (SYSAD4), U10.64 (SYSAD4)
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

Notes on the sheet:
clock multiplier
R3000 CPU
RCP
weird tracey thinger
5V regulator
2.5v Regulator
3.3v Switching Regulator
U3 - ??
RGB
Ls R U L D St Z
A Cd Cr B Cl Cu Rs
Analog Stick
Osc
Tact switch
R3000 decouple
RCP decouple
cont

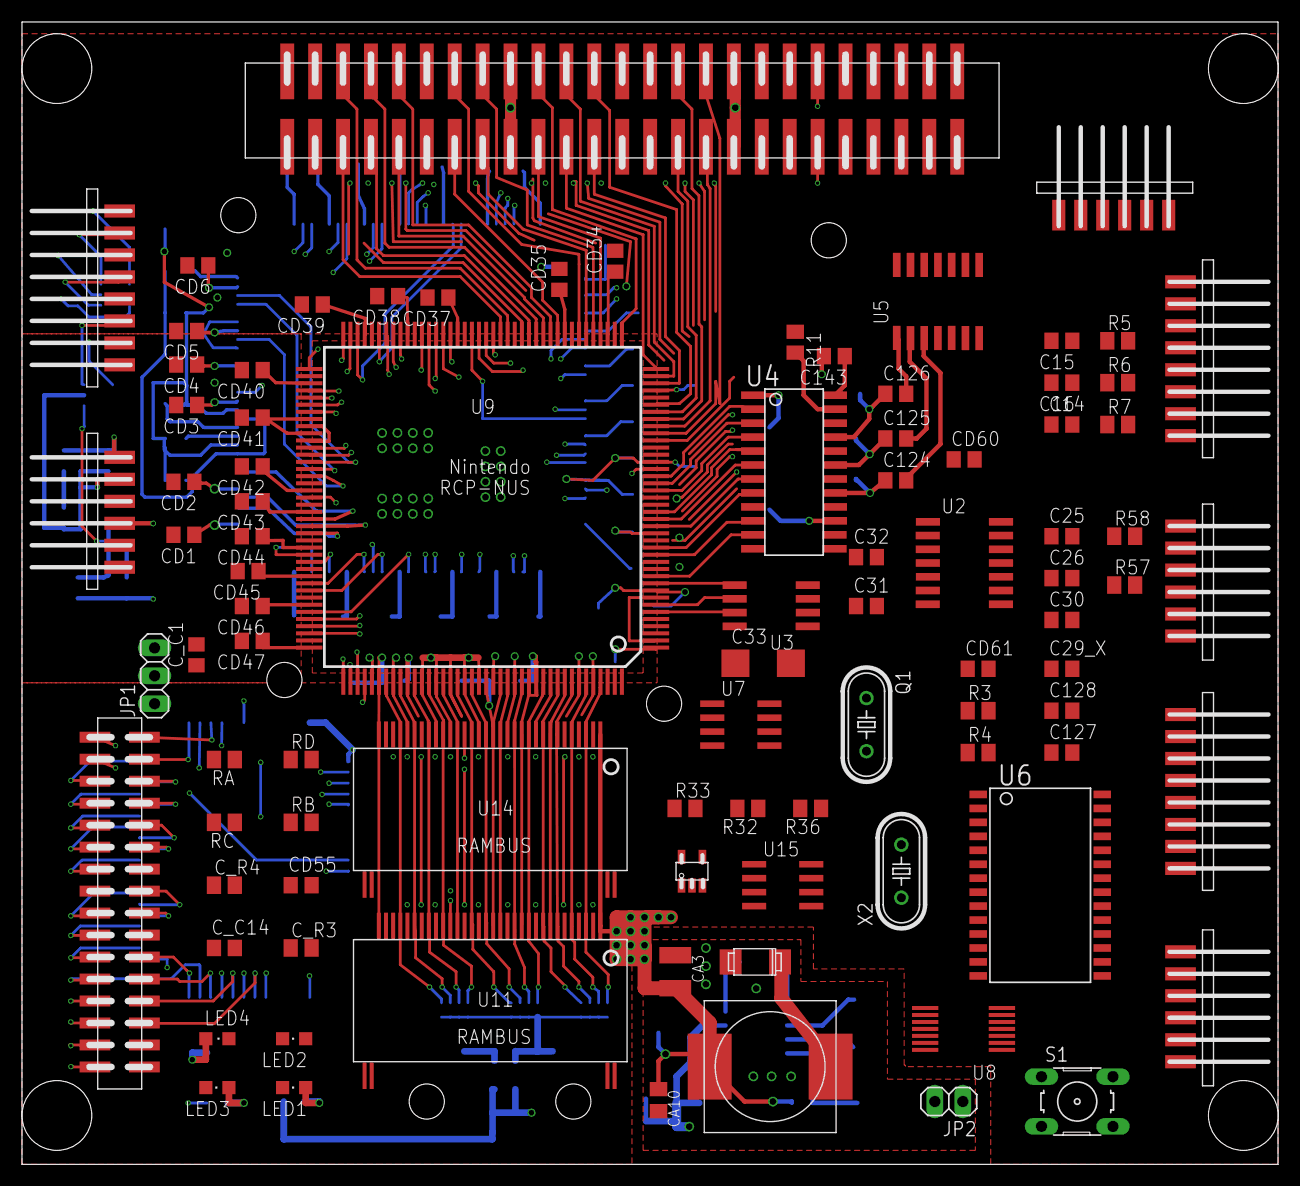
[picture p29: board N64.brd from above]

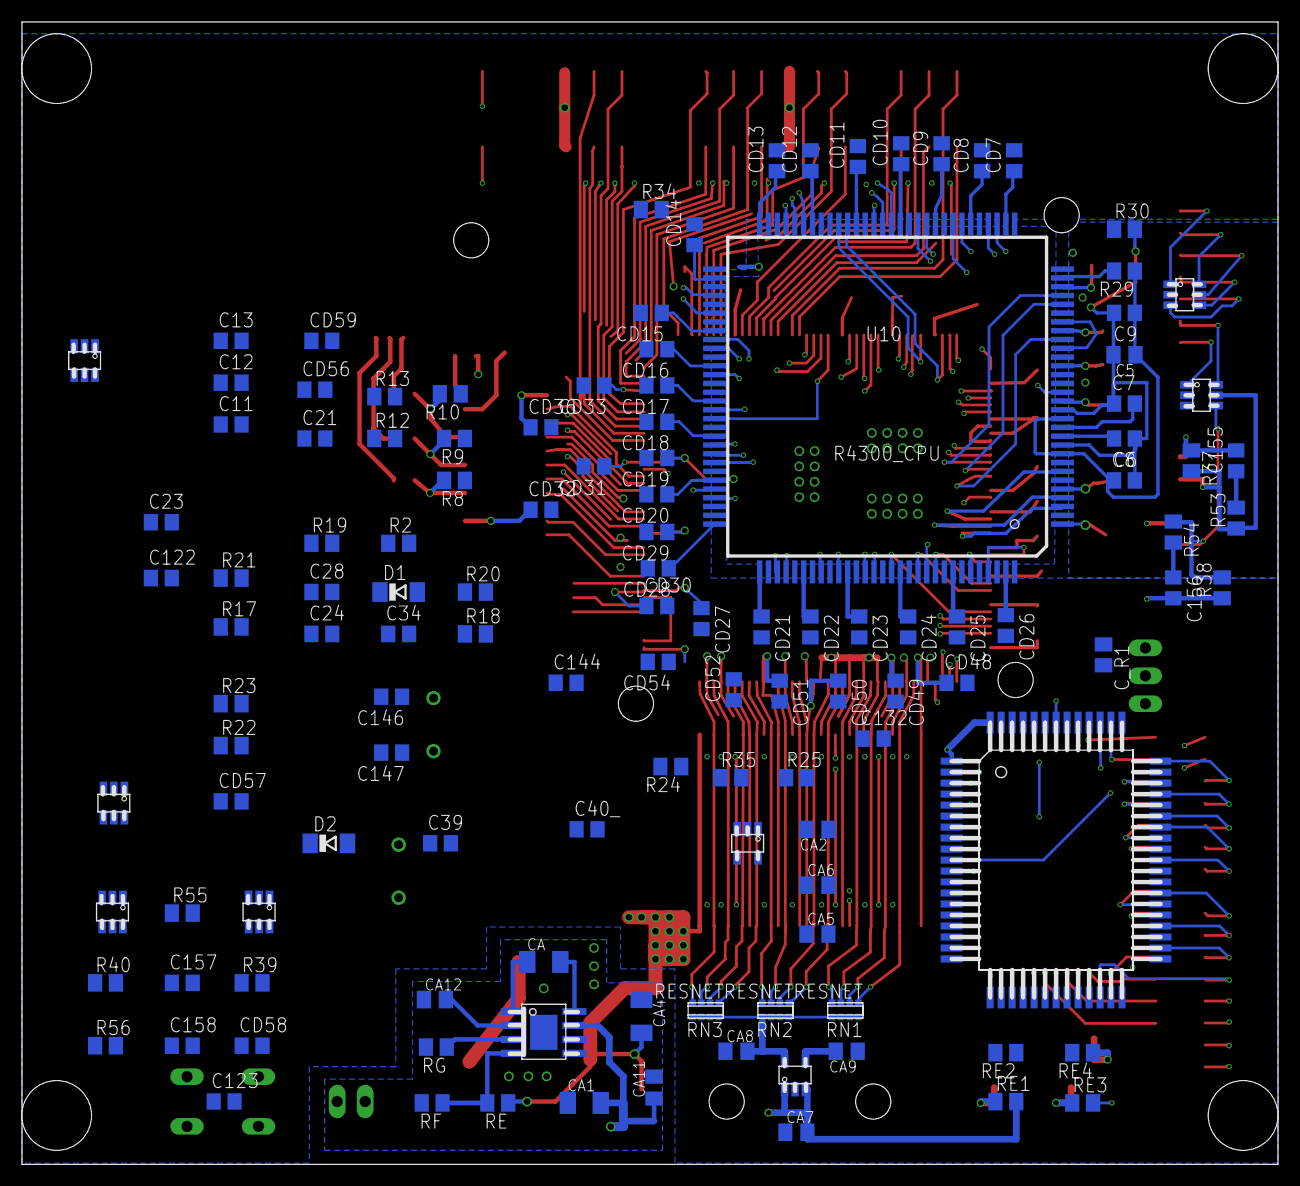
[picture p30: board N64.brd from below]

Board: 4 copper layers, 114.3 x 103.9 mm, 216 parts (125 on the bottom side), 239 nets.

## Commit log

2016-12-13 Reference files with EAGLE schematics, Board scans and Cartridge information found on the Internet
    [N64.brd, N64.sch, N64back2.brd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]
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2016-12-15 Slightly re-aligned to fit A1 paper size and better fit-on-screen view.
    [N64.sch]
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2016-12-18 Fixed ERC errors
    [n64-cpu-rcp.sch]
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2016-12-23 Crystal oscillator hole-through mount
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2016-12-23 Got rid of decoupler capacitors, not required at the moment
    [n64-cpu-rcp.sch]
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2016-12-24 Added 4 RDRAM chips and other small changes, WIP
    [n64-cpu-rcp.sch]
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2016-12-25 Messing around with Cart connector and RDRAM chips
    [n64-cpu-rcp.sch]
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2016-12-26 Move files to discrete projects, getting ready for memory expansion board project files
    [cpu-rcp.sch]
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2016-12-26 Separated projects into own directories as KiCAD application suggests
    [cpu-rcp.kicad_pcb, cpu-rcp.sch]
2016-12-26 Passives fixes
    [cpu-rcp.sch]
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2017-01-01 Messing around, rewiring cart edge and CPU interconnections
    [cpu-rcp.sch]
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2017-01-04 Corrections to CART EDGE power pins 22 and 23
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2017-01-04 Corrections to RDRAM EDGE for pins 5 and 20, power input and output trick
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2017-01-04 Fixed footprints for RDRAM EDGE
    [rcp-rdram.sch]
2017-01-05 Replaced own RESNET to R_Pack04 to match standart library footprints and 3D shape
    [rcp-rdram.sch]
2017-01-05 Reconfigured RESNET for the best fit on PCB
    [rcp-rdram.sch]
2017-01-05 Initial layout for board size of about 90x38mm
    [rcp-rdram.kicad_pcb]
2017-01-05 Lined up schematic, ERC passed, need additional checks just in case
    [cpu-rcp.sch]
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2017-01-06 Corrected NC pins to Passive type to be able to connect them to the GND
2017-01-06 Reconnected NC pins to the GND to not leave them floating
    [rcp-rdram.sch]
2017-01-06 Reconnected NC pins to the GND to not leave them floating, FIXED, ERC passed, NETLIST exported
    [rcp-rdram.sch]
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2017-01-10 Fixed GND connections to top side RAM chips
    [rcp-rdram.kicad_pcb]
2017-01-10 Adjusted track clearance to minimum of 0.15mm according to my PCB house design rules for better pricing
    [rcp-rdram.kicad_pcb]
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2017-01-10 Fixed Pin 13 name to VccP
2017-01-10 Moved power rails into hierarhical sheet, cleaned up external connections
    [cpu-rcp.sch]
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2017-01-10 Fixed Pin 15 name to Vcc
2017-01-12 Replaced with more appropriate drawning and 3D shape for better board layout
2017-01-12 Added decouplers for RCP, decouplers quantity matches power pin amount, moved power scheme to employ global labels
    [cpu-rcp-power.sch]
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2017-01-13 Peripherals moved to separate sheet, adjusted for new shape of MX8330
    [cpu-rcp.sch]
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2017-01-14 Replaced HC49U crystal with better 3D shape
    [rcp-rdram.kicad_pcb]
2017-01-15 Fixed local label /COLDRESET to global label on CART EDGE
    [cpu-rcp-peripherals.sch]
2017-01-15 Notes added for further CART EDGE split idea
    [cpu-rcp.sch]
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2017-01-15 Fixed missing INT2 pin to PIF connector
    [cpu-rcp-peripherals.sch]
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2017-01-18 Shortened pin counter
2017-01-18 Fixed RESNET pinout to match current footprint of CAY16-J4
    [rcp-rdram.sch]
2017-01-18 Redo signal termination (a major fail here), power supply lines, going to rewire for 0.1524mm (8mil) line clearance
    [rcp-rdram.kicad_pcb]
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2017-01-19 Board changed to L-shape, moved top side RDRAM chips to trick difficult to connect SOUT pin, rewired VREF resistor devider, other improvements
    [rcp-rdram.kicad_pcb]
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2017-01-20 Dimensions added, capacitors moved around, getting ready to shrink the board
    [rcp-rdram.kicad_pcb]
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2017-01-20 Tuned power track width to 0.37mm whenever possible
    [rcp-rdram.kicad_pcb]
2017-01-20 More stitchings for VREF line, minor text cleanups
    [rcp-rdram.kicad_pcb]
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2017-01-22 More convenient node name for better bash navigation
    [N64.brd, N64.sch, N64back2.brd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]
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2017-01-22 Footprints updated, using AMP connector for CART EDGE now
    [cpu-rcp-peripherals.sch]
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2017-01-24 Replaced VIDEO OUT connector with 4 pins Hirose DF13 series, there is no suitable 5 pins connectors, clock frequency notes added for MX8330
    [cpu-rcp-peripherals.sch]
2017-01-24 Now using Hirose DF13 1.25mm pitch SMT connector for power input
    [cpu-rcp-power.sch]
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2017-01-24 Fixed CART EDGE connector foorprint, replaced VIDEO OUT with Hirose DF52, the same type as AUDIO OUT
    [cpu-rcp-peripherals.sch]
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2017-01-26 Re-assigned FPC connectors, now using unified Molex 505110 series, see datasheet for details
    [cpu-rcp-peripherals.sch]
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2017-01-29 DC input footprint replaced with Molex 87833-0620
    [cpu-rcp-power.sch]
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2017-01-31 #COLDRESET D2 diode down to ENABLE signal added
    [cpu-rcp-power.sch]
2017-01-31 PIF-NUS seems to be completed, ERC passed, TODO joystick connections
    [cpu-rcp-peripherals.sch]
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2017-02-05 Better fit of VREF Resistor divider using new RDRAM EDGE pinout, some other small improvements related to the power rails
    [rcp-rdram.kicad_pcb]
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2017-02-05 Now using new RDRAM EDGE. RDRAM EDGE moved to external connections sheet
    [cpu-rcp-connectors.sch, cpu-rcp-power.sch, cpu-rcp.sch]
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2017-02-16 Prelimary 3D shape for RDRAM chip SHP-32 package, FreeCAD source file
    [shp-32.FCStd]
2017-02-16 Preliminary 3D shape for RDRAM chip SHP-32 package, FreeCAD source file
    [shp-32.FCStd]
2017-02-17 Updated model with fillet and pin 1 pocket
    [shp-32.FCStd]
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2017-02-19 All the pads were shortened according to datasheet specs, to save PCB space as well
2017-02-19 Slightly updated layout, now includes RDRAM 3D shapes to get better idea of how it looks, few minor changes to silkscreen were made
    [rcp-rdram.kicad_pcb]
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2017-02-19 Fixed disappearing after export to VRML
    [molex-502790-5091.FCStd]
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2017-02-22 Initial FreeCAD design for QFP-160 package 3D shape
    [qfp-160.FCStd]
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2017-02-24 Replaced duplicate footprint
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2017-08-17 Reduced number of decoupling capacitors for both CPU and RCP
    [cpu-rcp-power.sch]
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2017-08-18 Corrected model for proper 3D display
    [rcp-rdram.kicad_pcb]
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2017-08-18 Adjusted to local 3D shape copies for consistent 3D view
    [cpu-rcp.kicad_pcb]
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2017-08-21 Design Rules set according to my Fab House, switching to 4 layer board
    [cpu-rcp.kicad_pcb]
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2017-08-21 New initial schematics for DAC and Amplifier section
    [rcp-snd.sch]
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2017-08-21 New Design Rules for my Fab, inner power layers added
    [cpu-rcp.kicad_pcb]
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2017-08-22 Corrected Audio Out for Digital interfacing
    [cpu-rcp-connectors.sch]
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2017-08-24 Capacitors size corrected
    [cpu-rcp-peripherals.sch]
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2017-08-24 PLL capacitors size corrected
    [cpu-rcp.sch]
2017-08-24 Reduced board size and made slight changes to components layout
    [cpu-rcp.kicad_pcb]
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2017-08-25 Decoupling capacitors added, sizes and values fixed
    [rcp-rdram.sch]
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2017-08-27 Re-arranged, rewired, changed sizes and renamed decoupling capacitors
    [rcp-rdram.sch]
2017-08-27 Newer version according to modified schematics, need slight updates on Silk Screen
    [rcp-rdram.kicad_pcb]
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2017-08-28 Finished 4 layer board with Gerber output settings
    [rcp-rdram.kicad_pcb]
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2017-08-28 Updated design rules for better fab pricing, corrected to comply DRC
    [rcp-rdram.kicad_pcb]
2017-08-28 Updated fabrication files with less expensive drill size
    [rcp-rdram-B.Cu.gbl, rcp-rdram-B.SilkS.gbo, rcp-rdram-Edge.Cuts.gm1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]
2017-08-29 R36 and C144 moved here for ENABLE signal
    [cpu-rcp-power.sch]
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2017-08-29 Changed ENABLE to ENABLE_CLK due to correction in ENABLE generation
    [cpu-rcp-connectors.sch]
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2017-08-29 ENABLE signal and U3 connection errata, ENABLE_CLK added
    [cpu-rcp-power.sch]
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2017-09-04 Added decoupling capacitors to fit each side of CPU and RCP equally
    [cpu-rcp-power.sch]
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2017-09-05 CART FLAT CABLE mirrored to match RCP-CART board, more alignments to other components
    [cpu-rcp.kicad_pcb]
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2017-09-06 VTERM power output added, C142 replaced with C81 for U12 LDO
    [cpu-rcp-power.sch]
2017-09-06 Wrong footprint
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2017-09-08 Fixing in progress for new CART EDGE footprint
    [rcp-cart.kicad_pcb]
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2017-09-10 Updated with Core Board picture, fixed other boards pictures
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2017-09-12 VTERM moved to inner 3V3 layer, added few GND stitch vias, board silkscreen signature
    [cpu-rcp.kicad_pcb]
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
